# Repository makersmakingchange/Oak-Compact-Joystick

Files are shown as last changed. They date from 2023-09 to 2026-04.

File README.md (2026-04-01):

 # Oak Compact Joystick

<!---  SUMMARY A brief summary of the project. What it does, who it is for, how much it costs.  --->
The Oak Compact Joystick is a medium sized proportional joystick that can be used for adaptive gaming. It has range of motion of approximately ±25° and requires 525 grams-force to fully deflect. This joystick has a cable with a 3.5 mm TRRS audio plug (i.e., headphone jack). It is compatible Microsoft Xbox Adaptive controller as well as the [Forest Joystick Mouse Hub](https://github.com/makersmakingchange/Forest-Joystick-Mouse-Hub) and the [Enabled Controller](https://makersmakingchange.com/project/enabled-controller/).

The Oak Compact Joystick can be used directly as a left or right thumbstick for the Microsoft Xbox Adaptive Controller (XAC) using the X1 or X2 analog input ports. It can also be used with the [Forest Joystick Mouse Hub](https://github.com/makersmakingchange/Forest-Joystick-Mouse-Hub) as a USB Gamepad or USB Mouse.

The Oak Compact Joystick has a set of easily swappable, modular toppers that can be added to make the joystick easier or more comfortable to use.

The Oak Compact Joystick is open assistive technology (OpenAT). Under the terms of the open source licenses, the device may be built, used, and improved upon by anyone.

The current version of the Oak Compact Joystick (v1.0) has been built and user tested.

<!---  PHOTO  --->
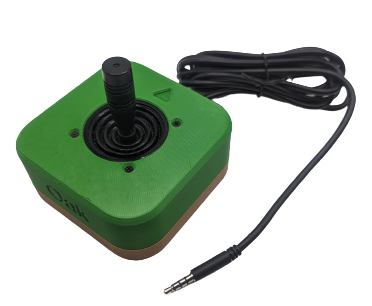
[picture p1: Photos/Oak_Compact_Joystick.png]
An Oak Compact Joystick in a green and brown enclosure.
 
 
<!---  Other available joysticks can be found through the [Joystick Selection Guide](https://makersmakingchange.com/resource/analog-joystick-selection-guide/) --->

Makers Making Change Assistive Device Library Listing: https://www.makersmakingchange.com/s/product/oak-compact-joystick/01tJR00000092x3YAA

## OpenAT Joysticks
This design is part of the [OpenAT Joystick Project](https://github.com/makersmakingchange/OpenAT-Joysticks), a collection of open source designs for digital access and adapted gaming.  

## How to Obtain an Oak Compact Joystick
There are several options for obtaining the device.

### 1. Do it Yourself (DIY) or Do it Together (DIT)

This is an open-source assistive technology, so anyone is free to build it. All of the files and instructions required to build the Oak Compact Joystick are contained within this repository.

### 2. Request a build of this device

If you would like to obtain an Oak Compact Joystick, you may submit a build request through the [MMC Library Listing](https://www.makersmakingchange.com/s/product/oak-compact-joystick/01tJR00000092x3YAA). The requestor is responsible for the cost of materials and any shipping.

### 3. How to build this device for someone else
If you have the skills and equipment to build this device, and would like to donate your time to create the device for someone who needs it, visit the [MMC Maker Wanted](https://makersmakingchange.com/maker-wanted/) section.

## Getting Started

### 1. Read the Makers Checklist

The Makers Checklist in the [Maker Guide](/Documentation/Oak_Joystick_Maker_Guide.pdf) contains a list of tasks to complete to build the device.

### 2. Order the Off-The-Shelf Components

The [Oak Joystick Bill of Materials](/Documentation/Oak_Joystick_BOM.csv) lists all of the parts and components required to build the Oak Compact Joystick.

### 3. Print the 3D Printable components

Print the components needed for the Oak Compact Joystick. Make sure to ask the user if they would like any of the optional prints such as toppers or mount adapters. Refer to the [OpenAT Joystick Setup Guide](https://github.com/makersmakingchange/OpenAT-Joysticks/Resources/OpenAT_Joystick_Setup_Guide.pdf) for detailed mounting options.

The 3D print files for the mounting adapters are located on the [OpenAT Joystick Repository](https://github.com/makersmakingchange/OpenAT-Joysticks/tree/main/Mounting%20Adapters)

All of the files and individual print files can be in the [/Build_Files/3D_Printing_Files](/Build_Files/3D_Printing_Files/) folder.

### 4. Assemble the Oak Compact Joystick

Reference the [Maker Guide](/Documentation/Oak_Joystick_Maker_Guide.pdf) for the tools and steps required to build each portion.

## Files
### Documentation
| Document | Version | Link |
|---|---|---|
| Design Rationale | 1.0 | [Oak_Compact_Joystick_Design_Rationale](/Documentation/Oak_Joystick_Design_Rationale.pdf) |
| Bill of Materials | 1.0 | [Oak_Compact_Joystick_Bill_of_Materials](/Documentation/Oak_Joystick_BOM.csv) |
| Topper Sizing Guide  | 1.0 | [Oak_Compact_Joystick_Topper_Guide](/Documentation/Oak_Joystick_Topper_Guide.pdf)
| Maker Guide | 1.0 | [Oak_Compact_Joystick_Maker_Guide](/Documentation/Oak_Joystick_Maker_Guide.pdf) |
| User Guide | 1.0 | [Oak_Compact_Joystick_User_Guide](/Documentation/Oak_Joystick_User_Guide.pdf) |

### Design Files
<!--- DESIGN FILES If possible, include a copy of original design files to facilitate easy editing and customization. --->
 - [CAD Files](/Design_Files)

### Build Files
<!--- BUILD FILES This section lists links to the various files used to build the device. --->
 - [3D Printing Files](/Build_Files/3D_Printing_files)

## License
<!--- LICENSE Choose an appropriate license. We recommend an open-source hardware compatible license. --->
Everything needed or used to design, make, test, or prepare the Oak Compact Joystick is licensed under the CERN 2.0 Weakly Reciprocal license <https://ohwr.org/project/cernohl/wikis/Documents/CERN-OHL-version-2> (CERN-OHL-W).

Accompanying material such as instruction manuals, videos, and other copyrightable works that are useful but not necessary to design, make, test, or prepare the Oak Compact Joystick are published under a Creative Commons Attribution-ShareAlike 4.0 license <https://creativecommons.org/licenses/by-sa/4.0/> (CC BY-SA 4.0).

Copyright (c) 2023-2025 Neil Squire Society.

This repository describes Open Hardware:
 - Everything needed or used to design, make, test, or prepare the Oak Compact Joystick is licensed under the [CERN 2.0 Weakly Reciprocal license (CERN-OHL-W v2) or later](https://cern.ch/cern-ohl ) .
 - All software is under the [GNU General Public License v3.0 (GPL-3.0)](https://www.gnu.org/licenses/gpl.html).
 - Accompanying material such as instruction manuals, videos, and other copyrightable works that are useful but not necessary to design, make, test, or prepare the Oak Compact Joystick are published under a [Creative Commons Attribution-ShareAlike 4.0 license (CC BY-SA 4.0)](https://creativecommons.org/licenses/by-sa/4.0/) .

You may redistribute and modify this documentation and make products using it under the terms of the [CERN-OHL-W v2](https://cern.ch/cern-ohl).
This documentation is distributed WITHOUT ANY EXPRESS OR IMPLIED WARRANTY, INCLUDING OF MERCHANTABILITY, SATISFACTORY QUALITY AND FITNESS FOR A PARTICULAR PURPOSE.
Please see the CERN-OHL-W v2 for applicable conditions.

Source Location: https://github.com/makersmakingchange/Oak-Compact-Joystick

## Attribution
<!--- ATTRIBUTION Include any information related to the development of the design. This may include who identified the initial challenge, who contributed to the design --->
The documentation template was created by the Makers Making Change program of the Neil Squire Society and is used under a CC BY-SA 4.0 license. It is available at the following link: https://github.com/makersmakingchange/OpenAT-Template

### Contributors
- Stephen Moyer, Neil Squire Society. Design of hardware, enclosure, toppers. Documentation.
- Jake McIvor, Neil Squire Society. Testing and documentation.
- Tyler Fentie, Neil Squire Society. Testing.
- Josie Versloot, Neil Squire Society. Testing.

---

<!-- ABOUT MMC START -->
## About Makers Making Change
[Makers Making Change Logo](https://www.makersmakingchange.com/)

Makers Making Change is a program of [Neil Squire](https://www.neilsquire.ca/), a Canadian non-profit that uses technology, knowledge, and passion to empower people with disabilities.

Makers Making Change leverages the capacity of community based Makers, Disability Professionals and Volunteers to develop and deliver affordable Open Source Assistive Technologies.

 - Website: [www.MakersMakingChange.com](https://www.makersmakingchange.com/)
 - GitHub: [makersmakingchange](https://github.com/makersmakingchange)
 - Bluesky: [@makersmakingchange.bsky.social](https://bsky.app/profile/makersmakingchange.bsky.social)
 - Instagram: [@makersmakingchange](https://www.instagram.com/makersmakingchange)
 - Facebook: [makersmakechange](https://www.facebook.com/makersmakechange)
 - LinkedIn: [Neil Squire Society](https://www.linkedin.com/company/neil-squire-society/)
 - Thingiverse: [makersmakingchange](https://www.thingiverse.com/makersmakingchange/about)
 - Printables: [MakersMakingChange](https://www.printables.com/@MakersMakingChange)

### Contact Us
For technical questions, to get involved, or to share your experience we encourage you to [visit our website](https://www.makersmakingchange.com/) or [contact us](https://www.makersmakingchange.com/s/contact).
<!-- ABOUT MMC END -->

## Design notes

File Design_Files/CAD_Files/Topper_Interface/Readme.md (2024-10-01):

This folder contains the CAD Design files for the Oak Joystick Topper Interface.

The Topper_Interface is the portion that is built in to the Topper. It has an internal thread and can be used to create a custom topper.

The Topper_Collet is a collet that fits between the cylindrical portion of the Oak Joystick and the Topper_Nut.

The Topper_Nut is tightened into the topper. It has an external thread and a hexagonal portion to make it easier to grip / tighten.

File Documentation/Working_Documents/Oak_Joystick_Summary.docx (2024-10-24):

This document is intended to be a summary of a device to make it easier to add to the website.

# Product Information

## Product Name

Oak Compact Joystick

## Device Category

Adapted Toys

Aids for Daily Living (ADL)

Assistive Switches

Communication Aids (AAC)

Computer Access

Environmental Controls

Gaming

Keyguard

Kits

LipSyncs

Mounting

Recreation and Leisure

Seating and Positioning

Switch Interfaces

Writing Aids

## User Value Statement

If you're looking for a joystick that is robust, has a range of topper options, and can be used with any device that accepts an analog joystick input, the Oak Compact Joystick may help get to the root of your joystick needs.

## Designer

Stephen Moyer, Neil Squire Society

# Device Info

## Overview

## The Oak Joystick is a midsized joystick compatible with the XAC or other analog input joystick devices. It has a range of toppers which can be securely attached onto the joystick and removed for ease of modification.

## Disability Type

Select one or more disability types:

Agility / Dexterity

Arthritis

Cognitive

Hearing

Mobility

Mobility

Other

Pain

SCI

Vision

## Disability Type Description

Great for anyone looking for a more traditional joystick experience and feel, with the ability to apply a range of custom toppers to maximize comfort in use.

## How To Use

For full instructions please refer to the User Guide.

Usage

Using the Joystick

1. Plug the 3.5 mm TRRS cable from the joystick into the host device (such as the Xbox Adaptive Controller). If using the Xbox Adaptive Controller, plug it into X1 to use at the left joystick, or plug into X2 to use as the right joystick.
2. Ensure the arrow on the joystick is pointing in the “up/forward” direction, away from the user.
3. Mount the device if needed (see below).
4. Move joystick as you would with a standard controller. Estimated Cost

Compatibility

This device is compatible with the XAC, Enabled Controller, and any other device that accepts a TRRS analog joystick input.

The estimated material cost of the device:

$0 - $10

$11 - $25

$26 - $50

$51 - $100

$101 - $250

$250+

## Attribution

Hardware, topper, and enclosure design: Stephen Moyer, Neil Squire

The documentation template was created by Makers Making Change / Neil Squire and is used under a CC BY-SA 4.0 license. It is available at the following link: https://github.com/makersmakingchange/OpenAT-Template

# Maker Info

## Project Skills

3D Printing

Custom PCB

Electronics

Laser Cutting

Mechanics

Other

Software

Soldering

Woodworking

## Skills Description

This is an intermediate build requiring soldering and 3D printing.

## Tools Needed

3D Printer

Common Hand Tools

Common Power Tools

Laser Cutter

Soldering Iron

Specialized Tooling

## Print time (hrs)

4

## Assembly time (hrs)

1

## Build Instructions

For full instructions please refer to the Assembly Guide (https://github.com/makersmakingchange/Oak-Compact-Joystick/blob/v1.0/Documentation/Oak_Joystick_Maker_Guide.pdf).

Print Settings:

- 0.2mm Layer Height
- 20% infill
- Some optional parts require supports

## Download Link

https://github.com/makersmakingchange/Oak-Compact-Joystick/archive/refs/heads/v1.0.zip

## Project Link

https://github.com/makersmakingchange/Oak-Compact-Joystick/tree/v0.9

# License

## License

Hardware: CERN 2.0 Weakly Reciprocal license

Documentation: Attribution-ShareAlike4.0 International

© 2023 by Neil Squire Society. This work is licensed under the CC BY SA 4.0 License: http://creativecommons.org/licenses/by-sa/4.0 Files available at https://github.com/makersmakingchange/Oak-Compact-Joystick Page 1 of 2

V1.0.2 | October 2024 Oak Compact Joystick Summary

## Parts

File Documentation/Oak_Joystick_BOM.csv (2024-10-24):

Oak Compact Joystick |  |  |  |  |  |  |  | Unit Cost | Total Cost | Total Print time (hr) | Total filament (g)
Version: V1.0.2 |  | Last Updated: 2024-Oct-07 |  |  |  |  |  | $61.12 | $61.12 | 3.87 | 63.26
Commercial Parts
ID | Part Name | Supplier | QTY | QTY/PKG | $/PKG | PKG QTY | $/Unit | Extended | Total | Link
 | TRRS Audio Cable | DigiKey | 1 | 1 | $7.29 | 1 | $7.29 | $7.29 | $7.29 | https://www.digikey.ca/en/products/detail/tensility-international-corp/10-00341/2350244
 | Adafruit Mini Analog Joystick | DigiKey | 1 | 1 | $31.43 | 1 | $31.43 | $31.43 | $31.43 | https://www.digikey.ca/en/products/detail/adafruit-industries-llc/3102/6152821
 | Wire, 26 AWG, 1 ft | DigiKey | 1 | 1 | $0.72 | 1 | $0.72 | $0.72 | $0.72 | https://www.digikey.ca/en/products/detail/cnc-tech/1569-26-1-0500-005-1-TS/15853670
 | Screw, #4 self-tapping 3/8" length | DigiKey | 4 | 1 | $0.63 | 4 | $0.63 | $2.52 | $2.52 | https://www.digikey.ca/en/products/detail/serpac/6005/307599
 | Cable tie, 4" | DigiKey | 1 | 1 | $0.17 | 1 | $0.17 | $0.17 | $0.17 | https://www.digikey.ca/en/products/detail/3m/CT4NT18-M/2721151
 | Hex nut, M3 | DigiKey | 2 | 1 | $0.27 | 2 | $0.27 | $0.54 | $0.54 | https://www.digikey.ca/en/products/detail/keystone-electronics/4708/4499301
 | Digikey Shipping (<$100 order) | DigiKey | 1 | 1 | $8.00 | 1 | $8.00 | $8.00 | $8.00
 |  |  |  |  |  |  | $- | $- | $-
3D Printed Parts ESTIMATED PRICING USING 1KG ROLL COST: |  | $30.00
ID | Part | Material | QTY | Mass (g) / Unit | Time / Unit |  | Print Time (Min) | Estimated Price |  | Link
 | Oak Enclosure Top | PLA | 1 | 28 | 130 |  | 130 | $0.83
 | Oak Enclosure Bottom | PLA | 1 | 27 | 102 |  | 102 | $0.82
 | Joystick Camera Mount (Optional) | PLA | 0 | 9 | 54 |  | 0 | $0.26
 | Oak Topper Collet (Optional) | PLA | 1 | 1 | 9 |  | 9 | $0.03
 | Oak Topper Nut (Optional) | PLA | 1 | 4 | 20 |  | 20 | $0.12
 | Oak Topper Wrench (Optional) | PLA | 1 | 5 | 26 |  | 26 | $0.15
 | Small_Ball Topper | PLA | 0 | 10 | 23 |  | 0 | $0.30
 | Medium_Ball_Topper | PLA | 0 | 16 | 30 |  | 0 | $0.48
 | Large_Ball_Topper | PLA | 0 | 24 | 40 |  | 0 | $0.72
 | Small_Concave_Topper | PLA | 0 | 9 | 20 |  | 0 | $0.27
 | Medium_Concave_Topper | PLA | 0 | 11 | 24 |  | 0 | $0.33
 | Large_Concave_Topper | PLA | 0 | 13 | 28 |  | 0 | $0.39
 | Small_Convex_Topper | PLA | 0 | 5 | 12 |  | 0 | $0.15
 | Medium_Convex_Topper | PLA | 0 | 7 | 16 |  | 0 | $0.21
 | Large_Convex_Topper | PLA | 0 | 10 | 21 |  | 0 | $0.30
 | Small_Goalpost_Topper | PLA | 0 | 12 | 31 |  | 0 | $0.36
 | Medium_Goalpost_Topper | PLA | 0 | 15 | 36 |  | 0 | $0.45
 | Large_Goalpost_Topper | PLA | 0 | 17 | 40 |  | 0 | $0.51
 | Small_Stick_Topper | PLA | 0 | 29 | 75 |  | 0 | $0.87
 | Medium_Stick_Topper | PLA | 0 | 42 | 102 |  | 0 | $1.26
 | Large_Stick_Topper | PLA | 0 | 55 | 122 |  | 0 | $1.65
 |  |  |  |  |  |  |  | $-
Alternatives
ID | Part and description |  |  |  |  |  |  |  |  | Link
 | M3 hex nuts | Local hardware store
 | Wire, 24 or 26 AWG | Local hardware store
 | #4 3/8" screws | Digikey | 4 | 100 | $7.82 | 1 | $0.08 | $0.31 | $7.82 | https://www.amazon.ca/gp/product/B00GI86MW8
 | Hex nut, M3 | Digikey | 2 | 100 | $0.06 | 1 | $0.00 | $0.00 | $0.06 | https://www.digikey.ca/en/products/detail/b-f-fastener-supply/MHNZ-003/274973
 | JH-D202X-R4 Joystick | Adafruit |  |  |  |  |  |  |  | https://www.adafruit.com/product/3102
 | JH-D202X-R4 Joystick | Exiron - Amazon |  |  |  |  |  |  | 27.22 | https://www.amazon.ca/Exiron-Joystick-Potentiometer-JH-D202X-R2-Thermistor/dp/B07CWWM9WF
 | JH-D202X-R4 Joystick | Adafruit - Mouser |  |  |  |  |  |  | 28.93 | https://www.mouser.ca/ProductDetail/Adafruit/3102
 | JH-D202X-R4 Joystick | Yan's Tools Store - AliExpress |  |  |  |  |  |  | 8.2 | https://www.aliexpress.com/item/1005003469274285.html

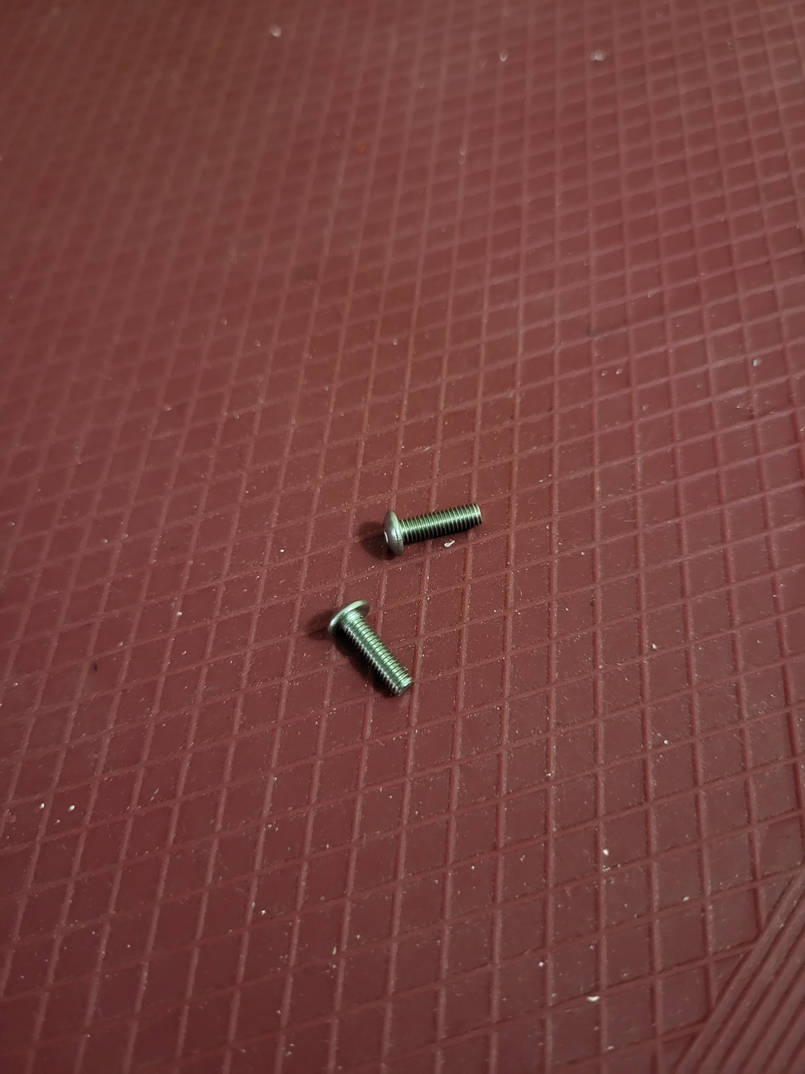
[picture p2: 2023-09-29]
Documentation/Working_Documents/Assets/Component_Photos/M3_screws.jpg

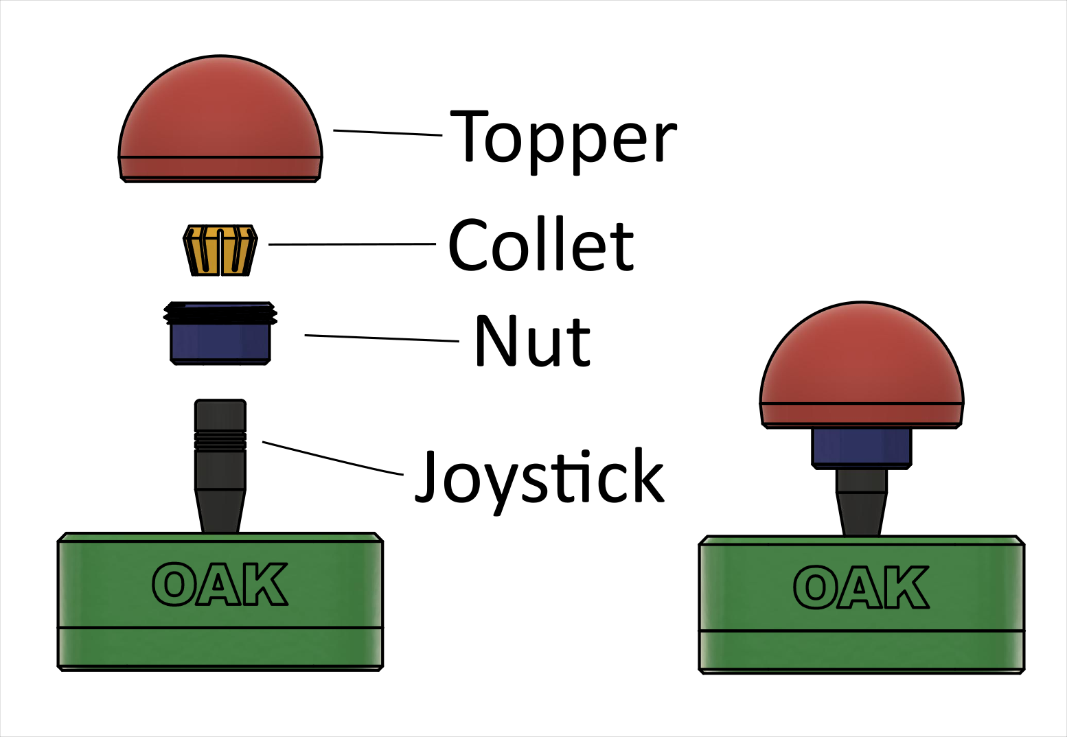
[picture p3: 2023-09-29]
Documentation/Working_Documents/Assets/Oak_Modular_Topper_Components.png

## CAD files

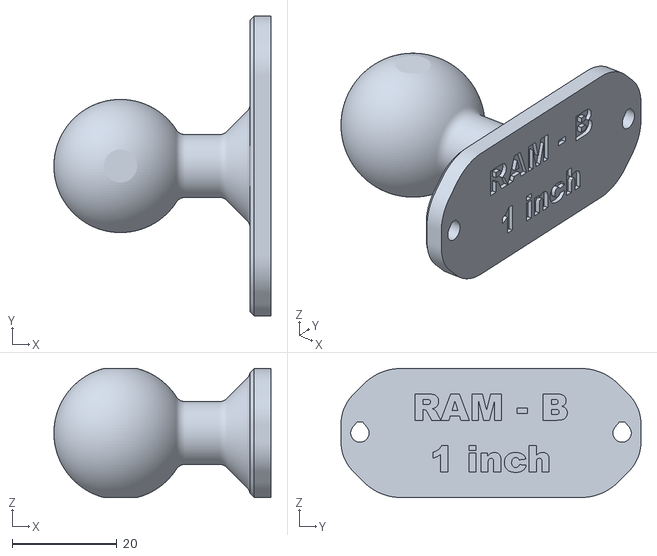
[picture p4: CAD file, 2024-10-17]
Build_Files/3D_Printing_Files/Joystick_RAM_B_Mount_Adapter.stl
41.4 x 57.2 x 24.6

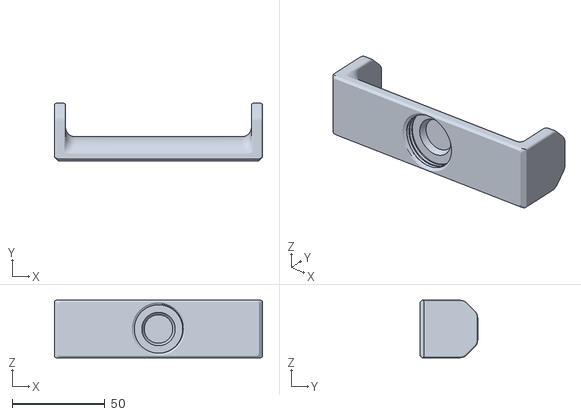
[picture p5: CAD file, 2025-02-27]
Build_Files/3D_Printing_Files/Toppers/Large/Large_Goalpost_Topper.stl
112.0 x 31.0 x 31.0

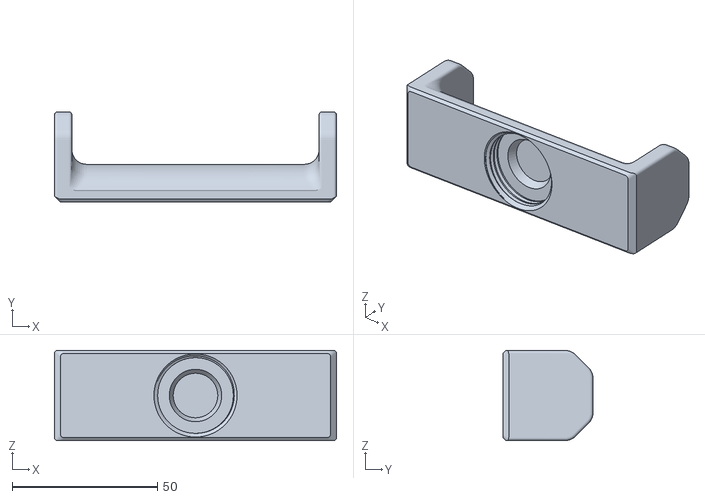
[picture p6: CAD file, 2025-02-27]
Build_Files/3D_Printing_Files/Toppers/Medium/Medium_Goalpost_Topper.stl
97.0 x 31.0 x 31.0

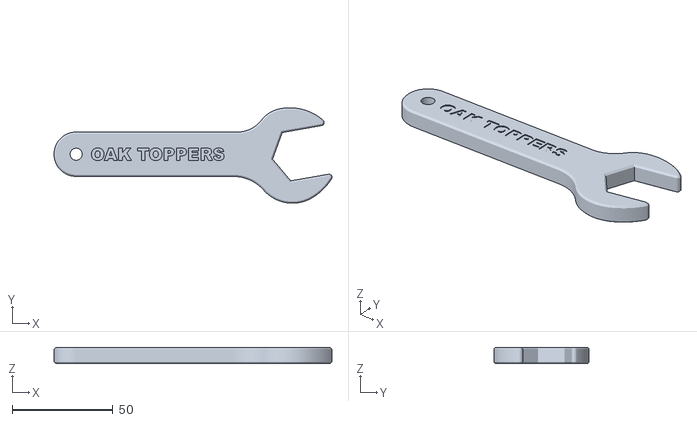
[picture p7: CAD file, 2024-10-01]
Build_Files/3D_Printing_Files/Toppers/Oak_Topper_Wrench.stl
137.7 x 47.2 x 8.00

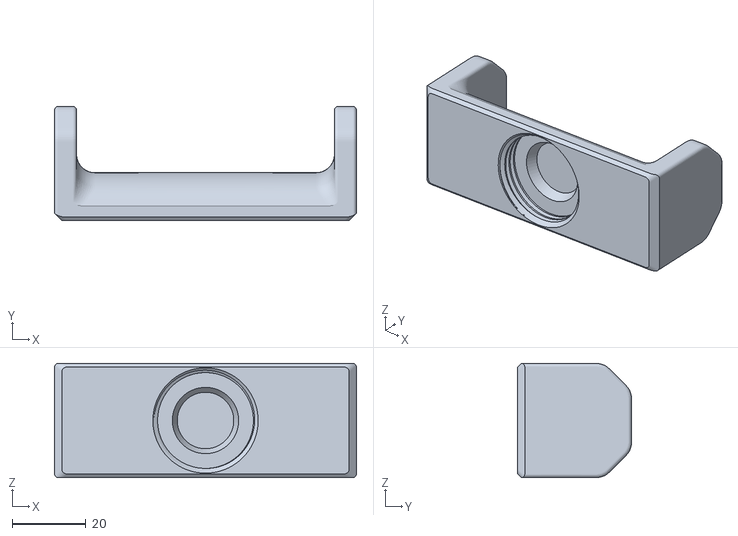
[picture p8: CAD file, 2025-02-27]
Build_Files/3D_Printing_Files/Toppers/Small/Small_Goalpost_Topper.stl
82.0 x 31.0 x 31.0

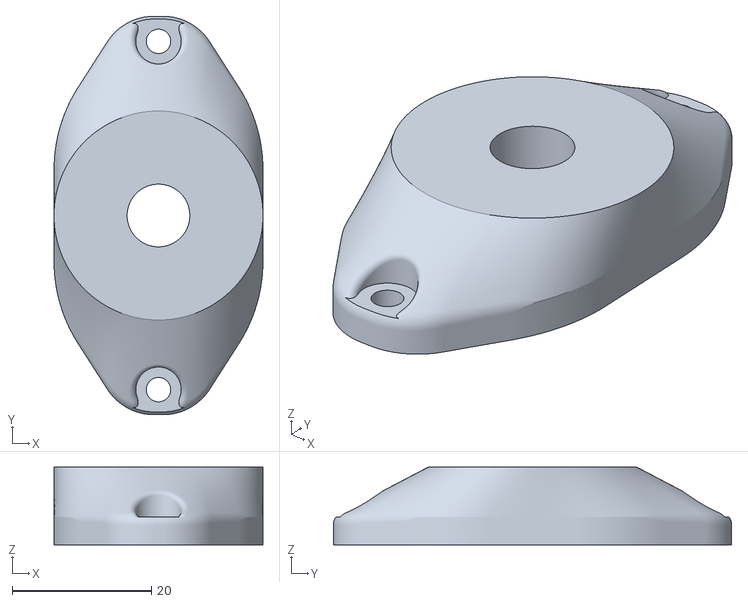
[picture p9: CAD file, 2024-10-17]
Build_Files/3D_Printing_Files/Joystick_Camera_Mount_Adapter.stl
30.0 x 57.2 x 11.1

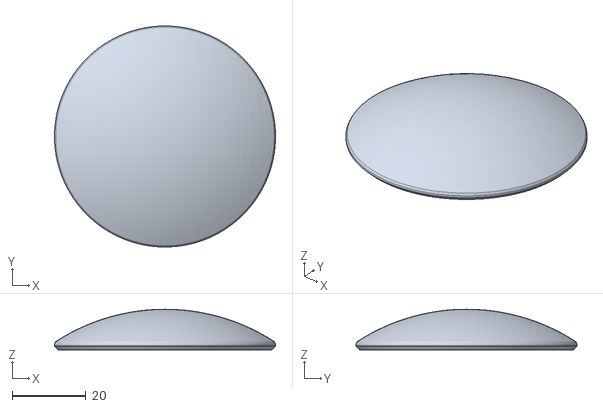
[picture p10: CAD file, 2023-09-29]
Build_Files/3D_Printing_Files/Toppers/Large/Large_Convex_Topper.stl
60.0 x 60.0 x 11.0

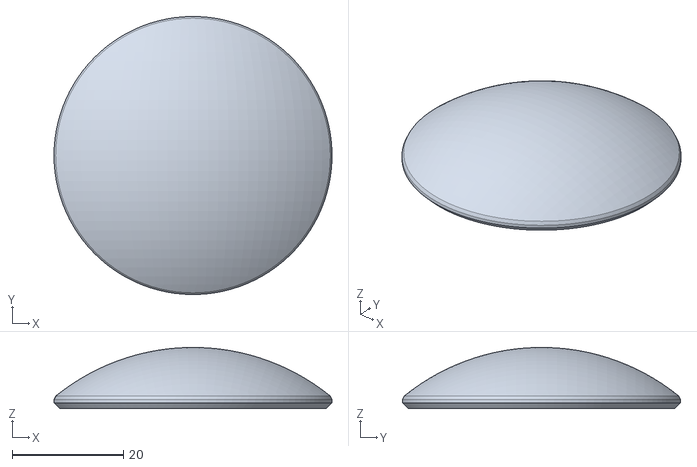
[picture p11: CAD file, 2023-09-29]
Build_Files/3D_Printing_Files/Toppers/Medium/Medium_Convex_Topper.stl
50.0 x 50.0 x 11.0

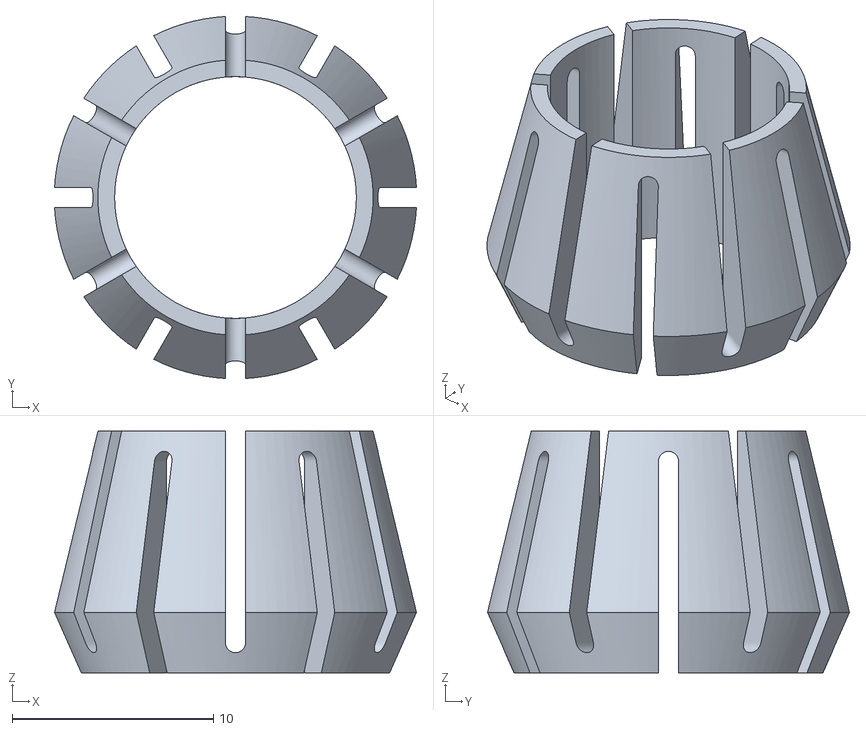
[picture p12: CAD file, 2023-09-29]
Build_Files/3D_Printing_Files/Toppers/Oak_Topper_Collet.stl
18.0 x 18.0 x 12.0

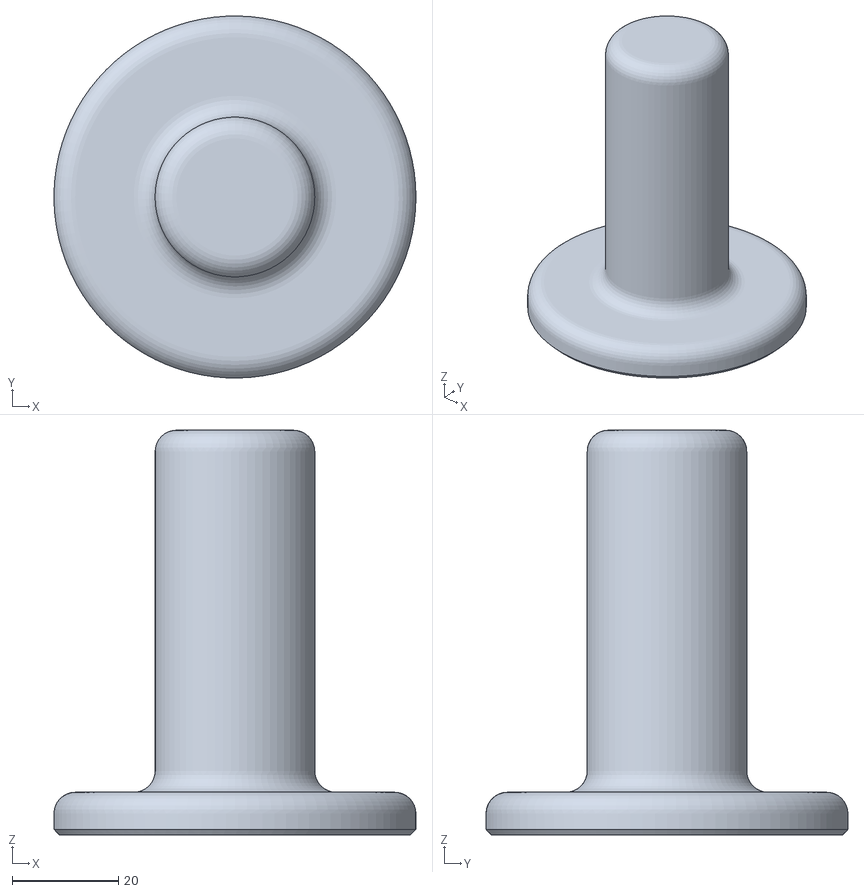
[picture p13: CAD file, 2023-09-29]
Build_Files/3D_Printing_Files/Toppers/Small/Small_Stick_Topper.stl
68.0 x 68.0 x 76.0

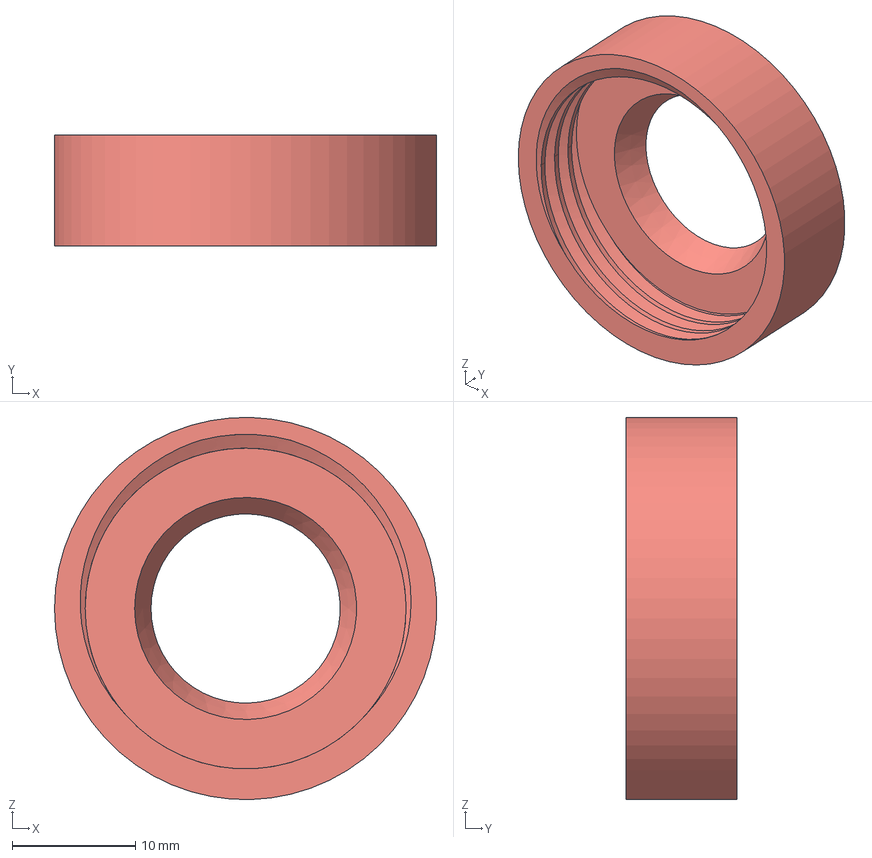
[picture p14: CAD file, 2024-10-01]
Design_Files/CAD_Files/Topper_Interface/Oak_Topper_Interface.step
31.0 x 9.00 x 31.0 mm

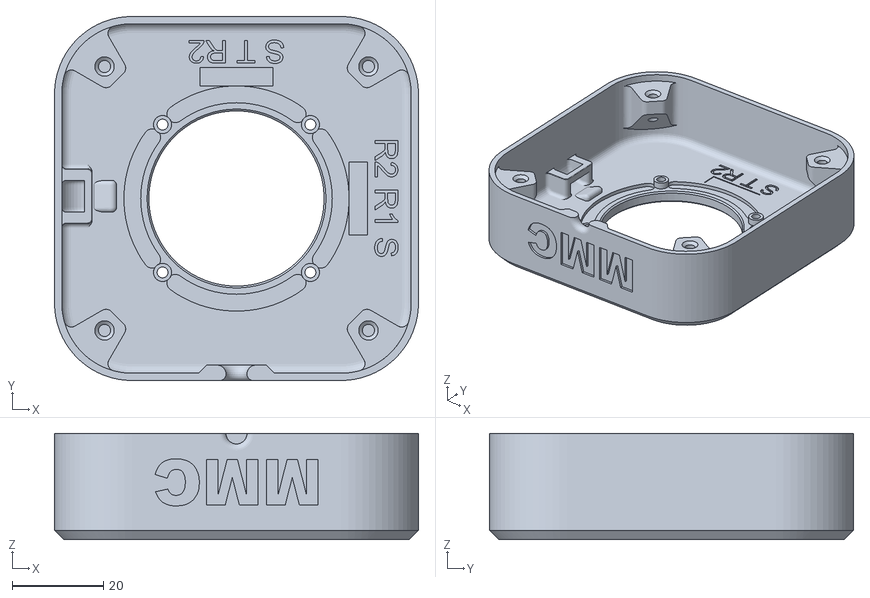
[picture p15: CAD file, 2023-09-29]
Build_Files/3D_Printing_Files/Oak_Enclosure_Top.stl
80.0 x 80.0 x 23.3

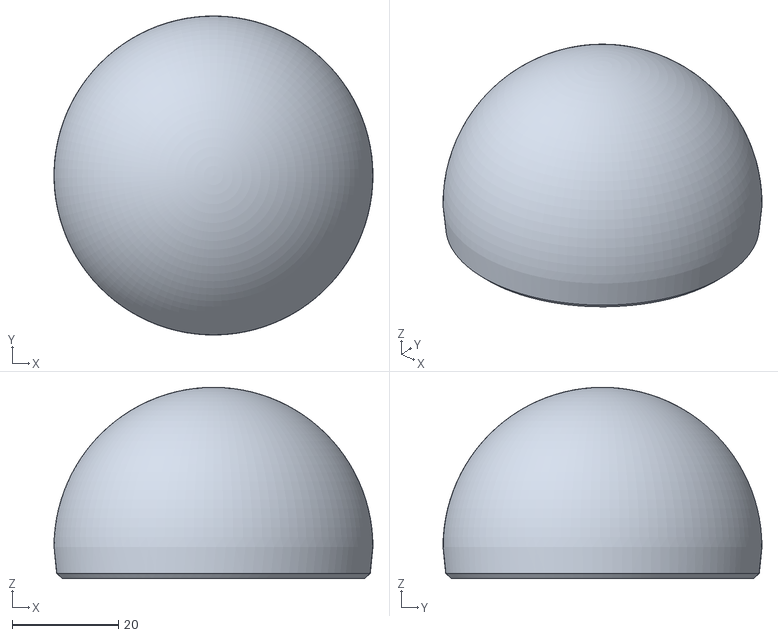
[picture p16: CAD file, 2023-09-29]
Build_Files/3D_Printing_Files/Toppers/Large/Large_Ball_Topper.stl
60.0 x 60.0 x 36.0

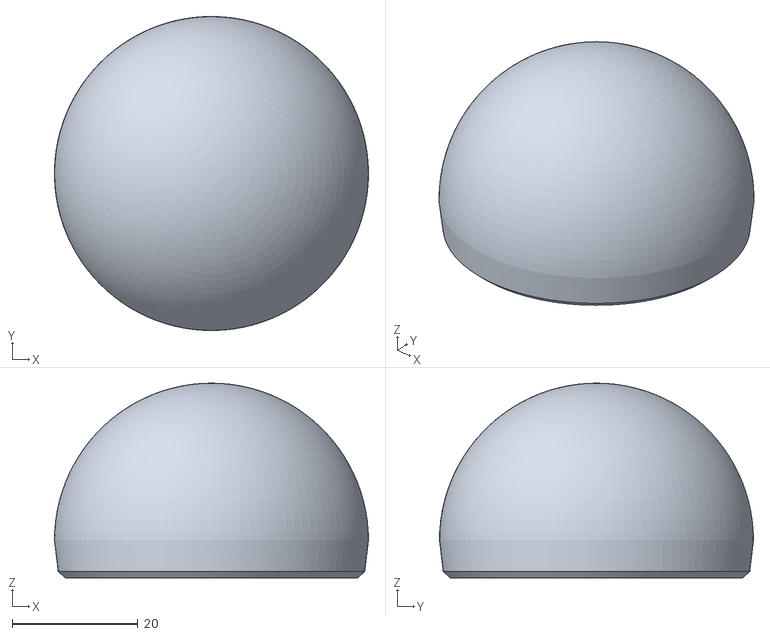
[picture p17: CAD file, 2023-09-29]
Build_Files/3D_Printing_Files/Toppers/Medium/Medium_Ball_Topper.stl
50.0 x 50.0 x 31.0

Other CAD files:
Design_Files/CAD_Files/Topper_Interface/Oak_Topper_Wrench.step
Build_Files/3D_Printing_Files/Toppers/Small/Small_Ball_Topper.stl
Design_Files/CAD_Files/Topper_Interface/Oak_Topper_Collet.step
Build_Files/3D_Printing_Files/Oak_Enclosure_Bottom.stl
Build_Files/3D_Printing_Files/Toppers/Large/Large_Concave_Topper.stl
Build_Files/3D_Printing_Files/Toppers/Large/Large_Stick_Topper.stl
Build_Files/3D_Printing_Files/Toppers/Medium/Medium_Concave_Topper.stl
Build_Files/3D_Printing_Files/Toppers/Medium/Medium_Stick_Topper.stl
Build_Files/3D_Printing_Files/Toppers/Oak_Topper_Nut.stl
Build_Files/3D_Printing_Files/Toppers/Small/Small_Concave_Topper.stl
Build_Files/3D_Printing_Files/Toppers/Small/Small_Convex_Topper.stl
Design_Files/CAD_Files/Joystick RAM Mount Adapter v5.f3d
Design_Files/CAD_Files/Joystick_Camera_Mount Narrow v3.f3d
Design_Files/CAD_Files/Oak_Compact_Joystick_Enclosure.f3d
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

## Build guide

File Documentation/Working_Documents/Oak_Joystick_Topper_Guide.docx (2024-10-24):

# What is a topper?

A topper is any support, grip, or other structure added to the joystick to make it easier and more comfortable to use the joystick. Toppers can be made of a variety of materials and be customized to the user.

The Oak Joystick has a modular topper that can be easily swapped. There are three parts to the modular topper: the topper, a collet, and a nut. A variety of topper styles are available and different sizes of each. It is also possible to create a topper with a custom style or size. A wrench tool is available to make it easier to tighten and loosen the nut.

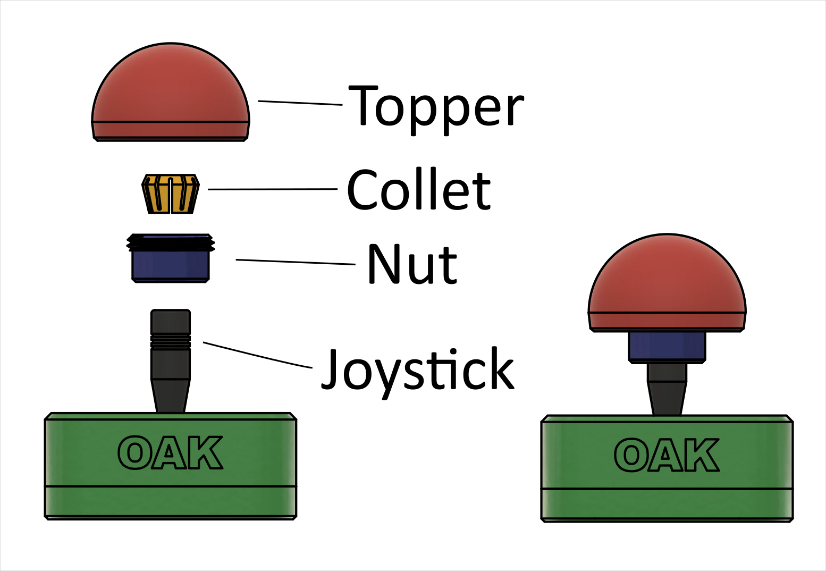
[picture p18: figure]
Oak Modular Topping system diagram

# What styles of toppers are there?

There are currently five styles of 3D printable topper: a hemispheric ball topper, a concave disc topper, a convex disc topper, a goalpost topper, and a stick topper.

Table 1. Topper Styles

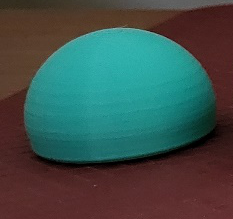
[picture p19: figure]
A photo of the ball, concave, convex, goalpost, and stick toppers from left to right printed in teal PLA.
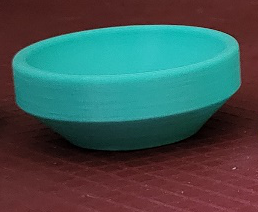
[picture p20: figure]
A photo of the ball, concave, convex, goalpost, and stick toppers from left to right printed in teal PLA.
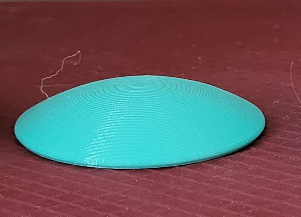
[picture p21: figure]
A photo of the ball, concave, convex, goalpost, and stick toppers from left to right printed in teal PLA.
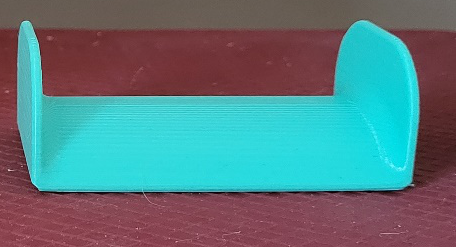
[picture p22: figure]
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
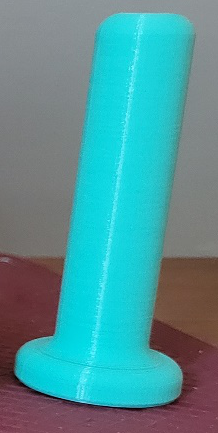
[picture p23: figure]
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

Ball | Concave | Convex | Goalpost | Stick

# Which topper will be best for me?

The five topper styles are available in small, medium, and large sizing. Dimensions and scaled printouts are available to select which size is best for you.

## Ball Topper

The ball topper is ideal for someone who wants a large grip or larger target to hit to move the joystick. Note that this topper is the top half of a ball, not a full ball.

Topper | Dimension | Small | Medium | Large | Image
Ball Topper | Diameter [mm] | 40 | 50 | 60

## Concave Disc Topper

That concave disc is best for someone without the capability to grip the joystick or other toppers. This topper is like a small cup that you can push on from the inside. It would be ideal for users who want to use their chin, or heel.

Topper | Dimension | Small | Medium | Large | Image
Concave Topper | Diameter [mm] | 40 | 50 | 60

## Convex Disc Topper

Topper | Dimension | Small | Medium | Large | Image
Convex Topper | Diameter [mm] | 40 | 50 | 60

The convex disc is ideal for someone with low grip capabilities but has good gross motor control and can rest their hand independently on the topper.

## Goalpost Topper

The goalpost topper is ideal for users who may not be able to independently put their hand on the topper, as the sidewalls will help to keep their hand on the joystick.

Topper | Dimension | Small | Medium | Large | Image

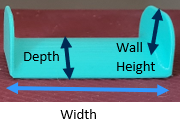
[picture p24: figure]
Goalpost topper showing width, depth, and wall height dimensions.

Goalpost Topper | Width [mm] | 70 | 85 | 100
| Depth [mm] | 31 | 31 | 31
| Wall Height [mm] | 15 | 18 | 20

## Stick Topper

The stick topper is a traditional joystick grip that essentially extends the existing stick of the joystick. It features a brim around the base to keep the user’s hand from slipping down the joystick as well.

Topper | Dimension | Small | Medium | Large | Image

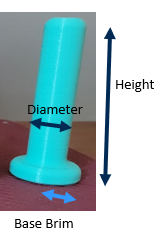
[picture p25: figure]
Stick topper showing diameter, height, and base brim dimensions.

Stick Topper | Grip diameter [mm] | 30 | 35 | 40
| Height [mm] | 70 | 85 | 100
| Base Brim [mm] | 15 | 20 | 25

## Custom Topper Sizes

If none of the pre-configured options works, the toppers can be further modified through the original CAD files (Fusion 360) if different dimensions are desired.

## Custom Topper Design

Custom toppers can be designed through CAD programs such as Fusion 360 to create a topper specific to you. The Design Rationale (https://github.com/makersmakingchange/Oak-Compact-Joystick/blob/v1.0/Documentation/Oak_Compact_Joystick_Design_Rationale.pdf) for the Oak Joystick contains all the relevant information to create a topper that will work with the current topper interface system, or to create a simple press-fit topper. The Collet.f3d file can also be expanded upon by designing a topper on and around the “Topper_Side” component.

Alternatively, other materials such as Instamorph, wood, clay, etc. can be used to create a custom topper.

# Topper Sizing Printouts

The following sheets can be printed out to see the actual size of the available toppers.

© 2023-2024 by Neil Squire Society. This work is licensed under the CC BY SA 4.0 License: http://creativecommons.org/licenses/by-sa/4.0 Files available at https://github.com/makersmakingchange/Oak-Compact-Joystick Page 1 of 2

V1.0.2 | October 2024 Oak Compact Joystick Topper Guide

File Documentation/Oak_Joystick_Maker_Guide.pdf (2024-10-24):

## Oak Compact Joystick

## MAKER GUIDE

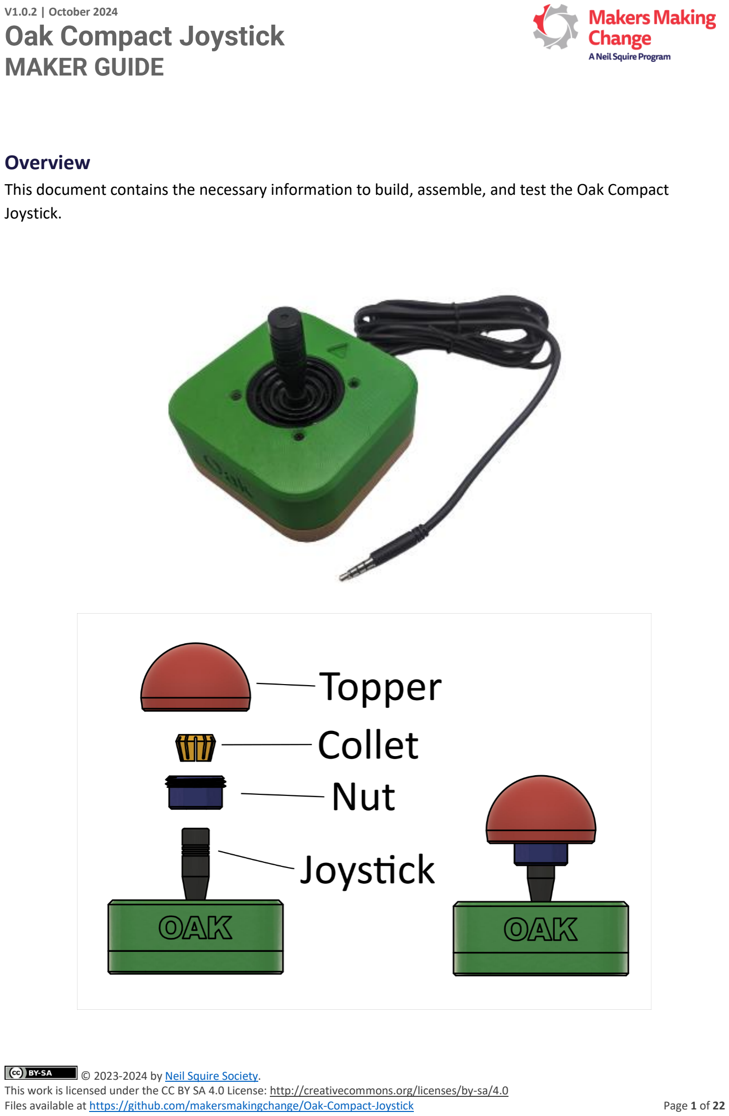
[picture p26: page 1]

V1.0.2 | October 2024

© 2023-2024 by Neil Squire Society. (https://www.neilsquire.ca/) This work is licensed under the CC BY SA 4.0 License: http://creativecommons.org/licenses/by-sa/4.0
Files available at https://github.com/makersmakingchange/Oak-Compact-Joystick | Page 1 of 22

### Overview

This document contains the necessary information to build, assemble, and test the Oak Compact Joystick.

## MAKER GUIDE

Files available at https://github.com/makersmakingchange/Oak-Compact-Joystick | Page 2 of 22

### Contents

## MAKER GUIDE

Files available at https://github.com/makersmakingchange/Oak-Compact-Joystick | Page 3 of 22

## MAKER GUIDE

Files available at https://github.com/makersmakingchange/Oak-Compact-Joystick | Page 4 of 22

This list provides an overview of the steps required to build and deliver the device.

### Maker To Do List

Read through the Maker Guide to become familiar with required components, tools, supplies, safety gear, and overall assembly steps.
Ask the user if they would if they have a device to connect the joystick to.
- Xbox Adaptive Controller (https://www.xbox.com/en-CA/accessories/controllers/xbox-adaptive-controller)
- Forest Joystick Mouse Hub (https://github.com/makersmakingchange/Forest-Joystick-Mouse-Hub)
- Enabled Controller Mini (https://github.com/makersmakingchange/Enabled-Controller-Mini/tree/main)
- Enabled Controller (https://github.com/milador/Enabled-Controller)
- Other Analog to USB joystick hub
Ask the user if they would like any joystick toppers. Reference the Topper Guide. Ask the user if they would like a specific mounting solution.
Talk to User about customization options (e.g., colour, any special requests, etc.). Order hardware components.
3D print all 3D printed components.
Gather tools, supplies, and safety equipment.
Assemble the device.
Test device.
Print “User Guide”

### Items to Give to User

Assembled, tested joystick Joystick toppers (if requested) Mounting Adapters (if requested) Printed “User Guide”

## MAKER GUIDE

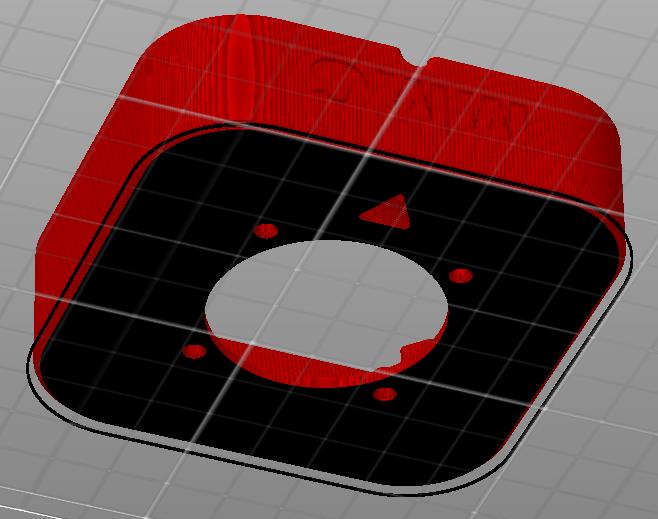
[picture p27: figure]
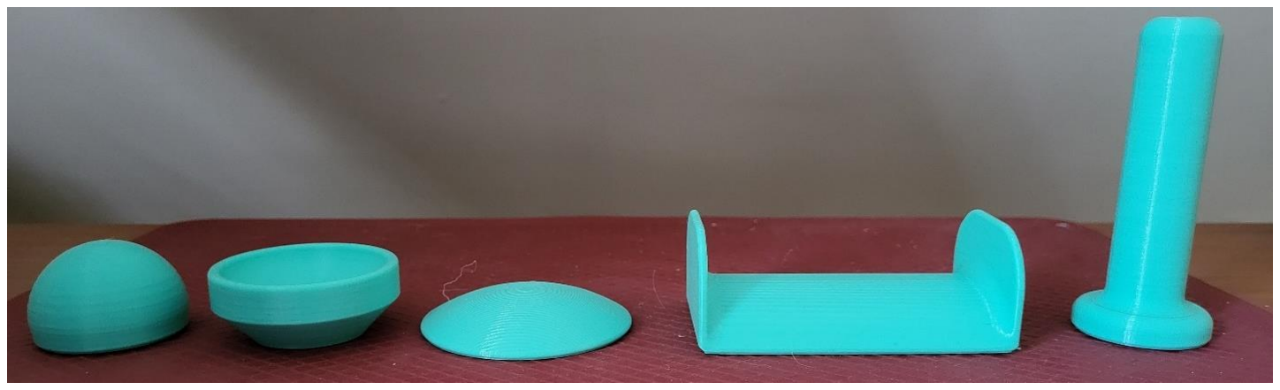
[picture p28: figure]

Files available at https://github.com/makersmakingchange/Oak-Compact-Joystick | Page 5 of 22

### Customization Guide

### Joystick

The enclosure can be printed in the user’s desired colour(s). Colour swaps can be done to further customize the joystick and make the forward arrow on the top stand out more.

### Toppers

3D printed joystick toppers can be added to the joystick. Current topper type include ball, concave, convex, goalpost, and stick (shown left to right). Each comes in sizes small, medium, and large, which can be seen in the Topper Guide, (https://github.com/makersmakingchange/Oak-Compact-Joystick/tree/v1.0/Documentation/Working_Documents/Oak_Joystick_Topper_Guide.docx) or can be further modified through the original design files. (https://github.com/makersmakingchange/Oak-Compact-Joystick/tree/v1.0/Design_Files)

### Mounting

Mount adapters can be added for custom mounting solutions. Current mounting options include nonslip pads, hook and loop fastener, and a ¼-20 camera mount adapter. Further mounting instructions can be found in the OpenAT Joystick Setup Guide. (https://github.com/makersmakingchange/OpenAT-Joysticks/Resources/OpenAT_Joystick_Setup_Guide.pdf)

## MAKER GUIDE

Files available at https://github.com/makersmakingchange/Oak-Compact-Joystick | Page 6 of 22

### 3D Printing Guide

### 3D Printing Summary

Metrics | Joystick Enclosure | Topper Interface
Total Print Time (min) | 4h4m | 0h56m
Total Number of Components | 2 | 2
Typical Total Mass (g) | 52 | 6
Typical Number of Print Setups | 1 | 1

### 3D Printing Settings

Joystick Enclosure - REQUIRED
Print File Name | Qty | Total Print Time (hr:min) | Mass (g) | Infill (%) | Support (Y/N) | Layer Height/ Nozzle Diameter(mm) | Notes
Oak_Enclosure_Top.stl | 1 | 2:22 | 29 | 20 | N | 0.2/0.4
Oak_Enclosure_Bottom.stl | 1 | 1:42 | 23 | 20 | N | 0.2/0.4

Oak Topper Interface – OPTIONAL, Required for Topper
Print File Name | Qty | Total Print Time (hr:min) | Mass (g) | Infill (%) | Support(Y/N) | Layer Height/ Nozzle Diameter(mm) | Notes
Oak_Topper_Nut.stl | 1 | 0:39 | 5 | 20 | N | 0.2/0.4
Oak_Topper_Collet.stl | 1 | 0:17 | 1.04 | 20 | N | 0.2/0.4
Oak_Topper_Wrench.stl | 1 | 0:26 | 5 | 20 | N | 0.2/0.4

Toppers* - OPTIONAL
Print File Name | Qty | Total Print Time (hr:min) | Mass (g) | Infill (%) | Support(Y/N) | Layer Height/ Nozzle Diameter(mm) | Notes
Medium_Ball_Topper.stl | 1 | 1:16 | 18 | 10 | N | 0.2/0.4 | Print with 4 perimeters
Medium_Concave_Topper.stl | 1 | 1:07 | 15 | 10 | N | 0.2/0.4 | Print with 4 perimeters
Medium_Convex_Topper.stl | 1 | 0:42 | 9 | 10 | N | 0.2/0.4 | Print with 4 perimeters

## MAKER GUIDE

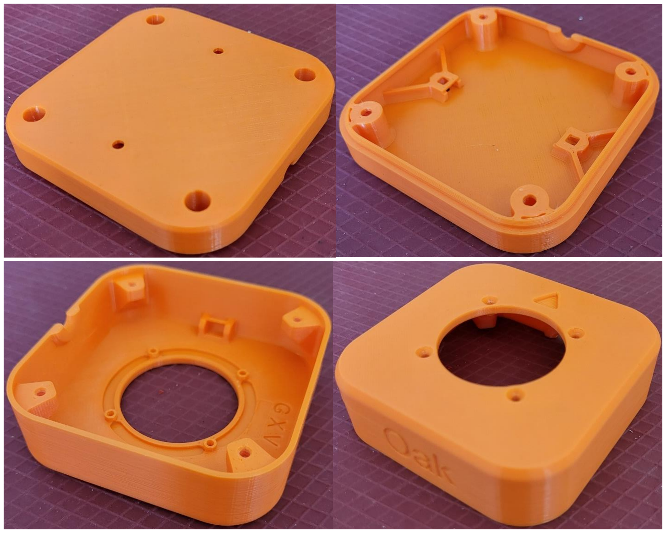
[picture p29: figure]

Files available at https://github.com/makersmakingchange/Oak-Compact-Joystick | Page 7 of 22
Medium_Goalpost_Topper.stl | 1 | 1:30 | 18 | 10 | N | 0.2/0.4 | Print with 4 perimeters
Medium_Stick_Topper.stl | 1 | 3:13 | 50 | 10 | N | 0.2/0.4 | Print with 4 perimeters

*Note that only the medium topper sizes are shown in the 3D printing Settings table. There are small
and large sizes available, as well as the original Fusion 360 files that can be modified to specific
dimensions.

### Post-Processing

- Remove any supports from the Camera mount adapter if it is printed.
- Clear any stringing in the collet if it is printed.

### Examples of Quality Prints

Photos of Enclosure 3D Prints

## MAKER GUIDE

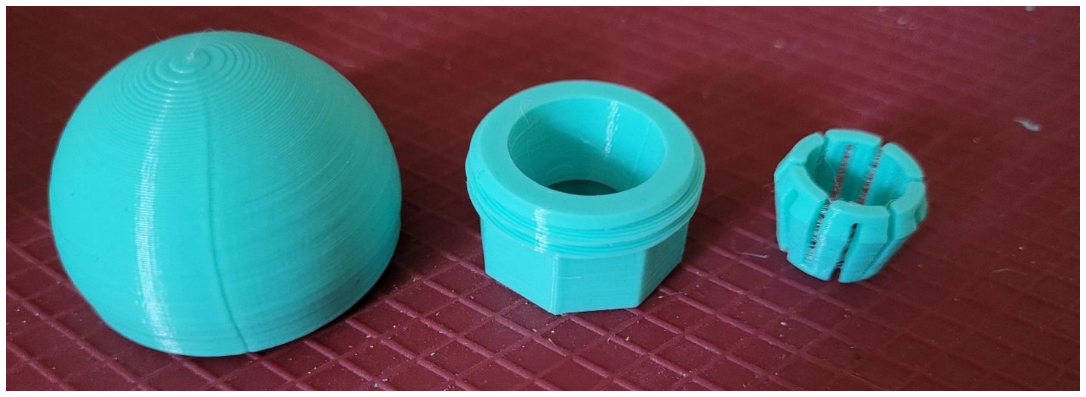
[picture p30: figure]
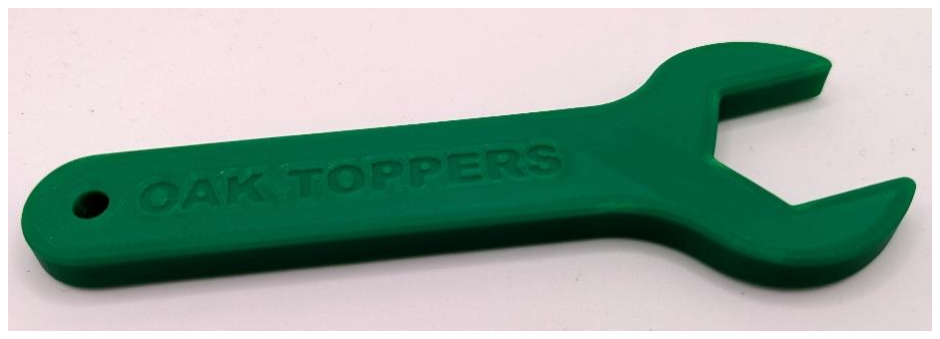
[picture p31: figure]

Files available at https://github.com/makersmakingchange/Oak-Compact-Joystick | Page 8 of 22

Photos of Topper 3D Prints

Photo of Wrench Topper

## MAKER GUIDE

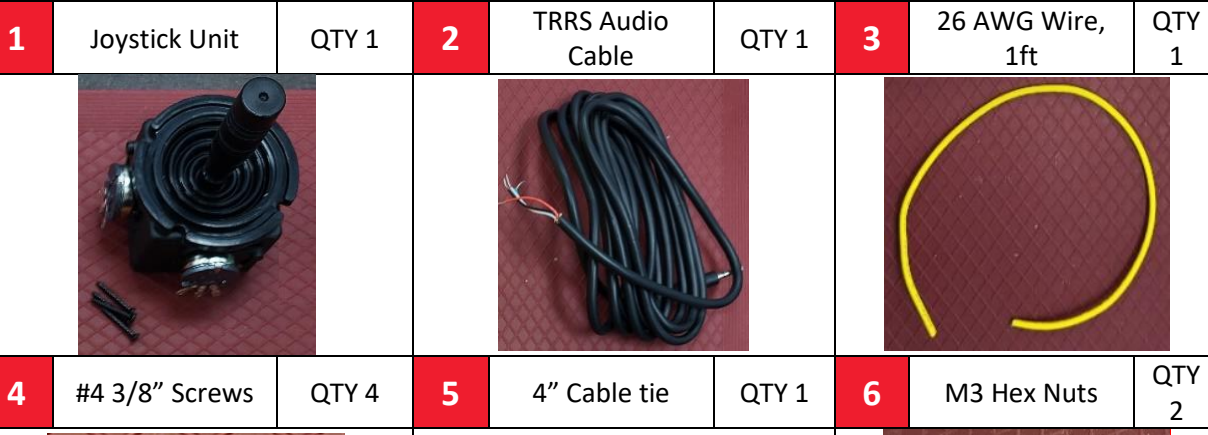
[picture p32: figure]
Joystick Unit; QTY 1; TRRS Audio; Cable; 26 AWG Wire, 1ft; #4 3/8” Screws; QTY 4; 4” Cable tie; M3 Hex Nuts; QTY

Files available at https://github.com/makersmakingchange/Oak-Compact-Joystick | Page 9 of 22

### Assembly Guide

### Required Components

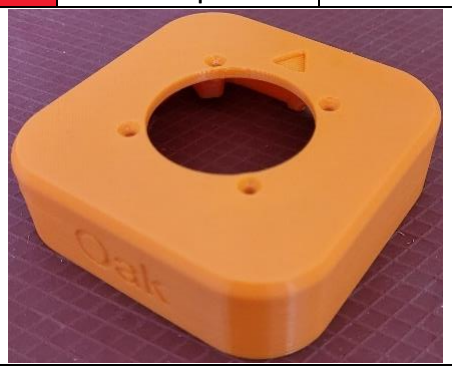
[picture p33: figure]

7

Oak Enclosure
Top | QTY 1 | 8

Oak Enclosure
Bottom | QTY 1

### Required Tools

- #1 Phillips Screwdriver
- Wire Cutters
- Wire Strippers
- Soldering Iron and Solder
- Multimeter (with continuity testing capabilities)

### Optional Tools

- Tweezers

### Required Personal Protective Equipment (PPE)

- Safety Goggles

## MAKER GUIDE

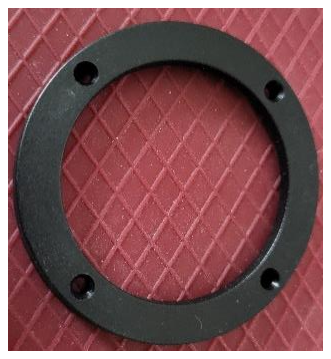
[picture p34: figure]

Files available at https://github.com/makersmakingchange/Oak-Compact-Joystick | Page 10 of 22

### Joystick Assembly

Step 1: Remove the Ring

The Adafruit Mini Analog Joystick comes with a ring that screws into the top. You will not need this ring and can dispose of it.

Note: Keep the screws that come with the joystick, do not throw them out.

Step 2: Prepare Audio Cable
If you are using the pre-prepared TRRS cable from DigiKey, pictured in the component list, you can skip this step.
If using a different cable, you’ll need to prepare the wires for soldering. Cut the TRRS cable to length (typically 1 m). Strip off approximately 3 cm of the outer insulation. Then separate the individual inner wires and strip off approximately 0.5 cm of insulation.
Step 3: Identify Audio Cable Wires
If using the pre-prepared DigiKey cable, you can skip this step.

If using a different cable, you need to identify which wires correspond to which parts of the plug. Use a multimeter or other continuity tester to confirm. Follow this guide for checking continuity (https://www.youtube.com/watch?v=T4p8UQZqh5U) to determine which wire corresponds to the Sleeve, Ring 1, Ring 2, and Tip of the TRRS cable plug. You can use the table below to write the corresponding colours for your cable.

TRRS Plug | Digikey cable | Your cable
Tip (T) | Red
Ring 1 (R1) | White
Ring 2 (R2) | Green
Sleeve (S) | Black

## MAKER GUIDE

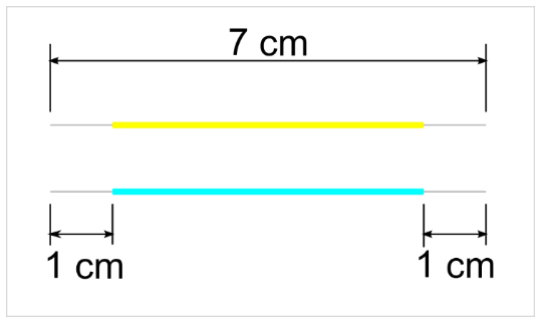
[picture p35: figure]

Files available at https://github.com/makersmakingchange/Oak-Compact-Joystick | Page 11 of 22
Step 4: Prepare Wires
Cut two pieces of wire, 7 cm long. Strip 1 cm off the ends of both wires. Twist each respective end of the wires to collect all the frayed wire strands into one. Choose one to be Wire A, and one to be Wire B.

Note: For this assembly guide, the yellow wire is Wire A and the blue wire is Wire B.

## MAKER GUIDE

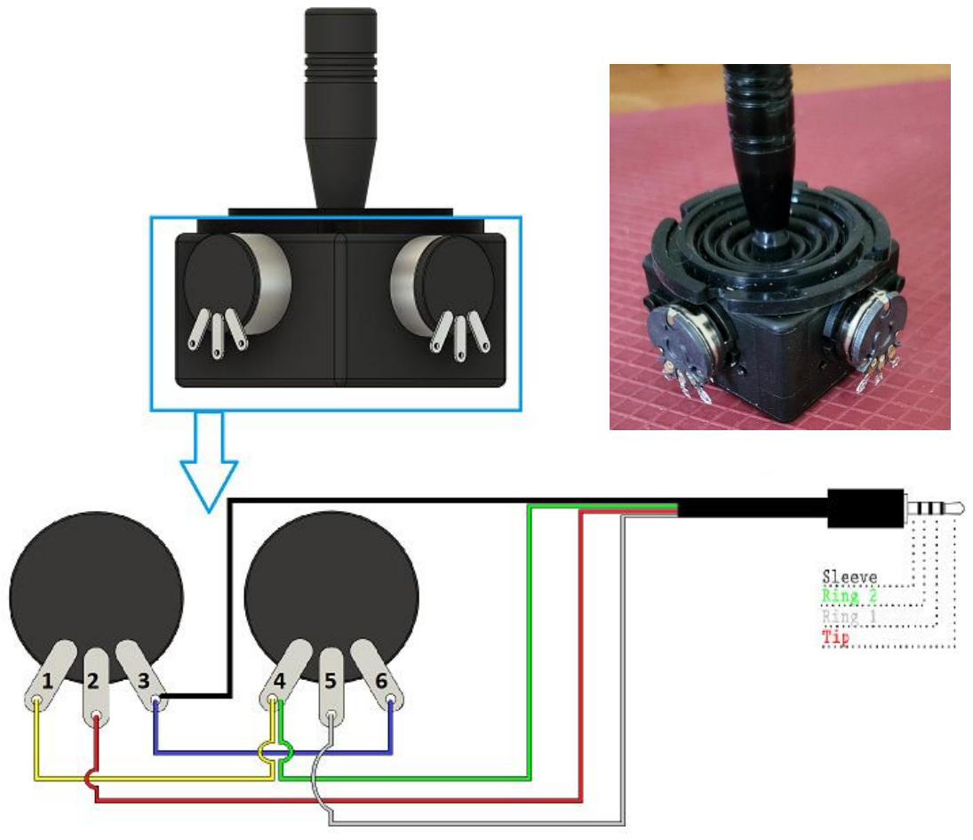
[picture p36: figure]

Files available at https://github.com/makersmakingchange/Oak-Compact-Joystick | Page 12 of 22
Step 5: Wire the Joystick
Wiring the joystick will follow the diagram below and will be broken down into multiple steps. With the joystick positioned with the two potentiometers facing you as shown, the pins are numbered 1 through 6 from left to right.

Figure 1. Joystick Wiring Guide. Image Remixed from Sparkfun, released under a CC BY 2.0 license.

Table 1: Oak Wiring

Potentiometer Pins | CONNECTION | Digikey TRRS Cable | Your TRRS Cable | Extra Wire
1 | PIN 4 | --- | ----- | Wire A
2 | Tip (T) | Red | | ----
3 | Sleeve (S) | Black | | Wire B
4 | Ring 2 (R2) | Green | | Wire A
5 | Ring 1 (R1) | White | | ----
6 | PIN 3 | ---- | ---- | Wire B

## MAKER GUIDE

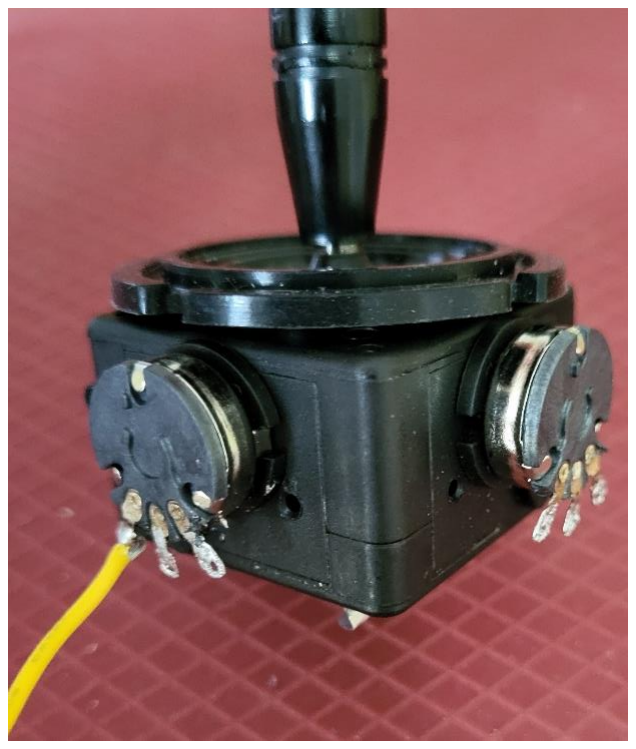
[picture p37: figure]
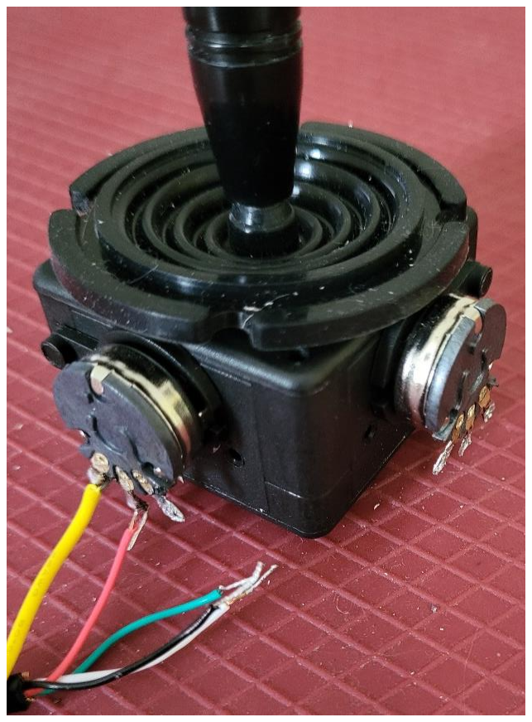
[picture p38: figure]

Files available at https://github.com/makersmakingchange/Oak-Compact-Joystick | Page 13 of 22
Step 5A: Wire and Solder Pin 1

Take Wire A and insert one end into Pin 1. Solder this into place.

Step 5B: Wire and Solder Pin 2

Take the red (tip) wire from the audio cable and insert it into pin 2. Solder this into place.

## MAKER GUIDE

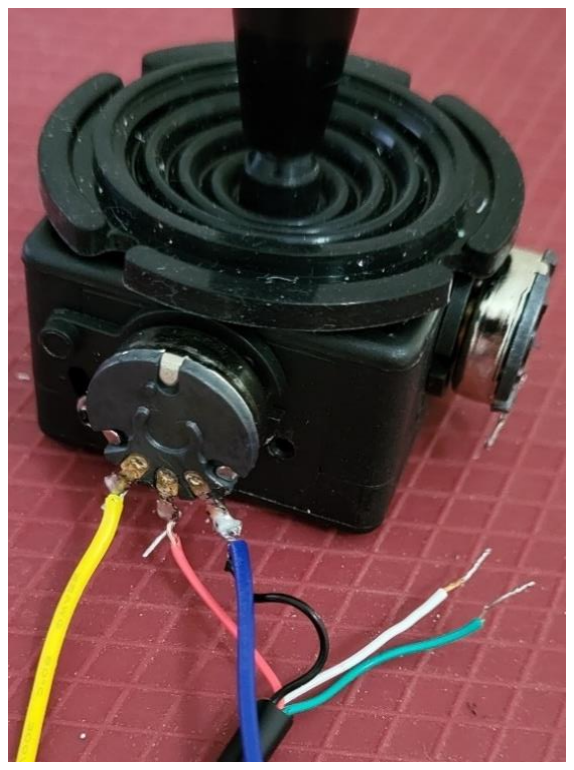
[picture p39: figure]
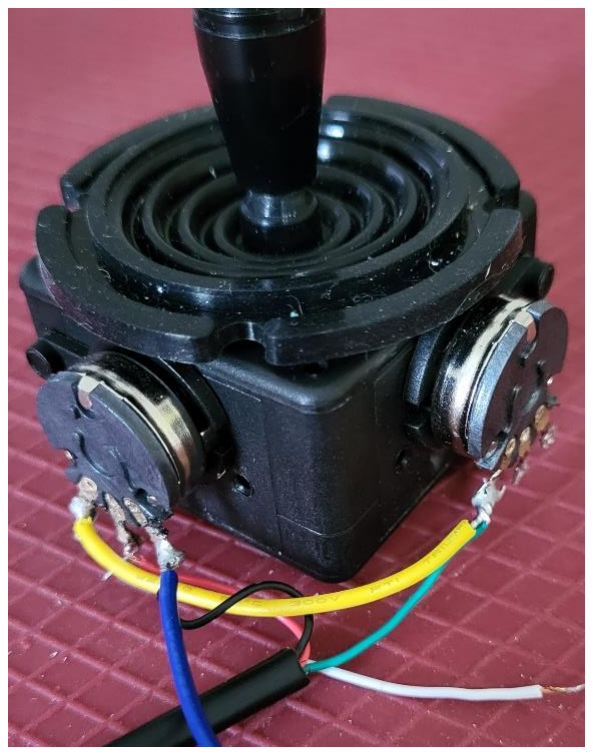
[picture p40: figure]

Files available at https://github.com/makersmakingchange/Oak-Compact-Joystick | Page 14 of 22
Step 5C: Wire and Solder Pin 3

Take the black (sleeve) wire from the audio cable and twist it together with one end of Wire B. Insert the twisted together portion of the wires into pin 3. Solder this into place.

Step 5D: Wire and Solder Pin 4

Take the free end of Wire A and twist it together with the green (Ring 2) wire from the audio cable. Insert these into pin 4 and solder into place.

## MAKER GUIDE

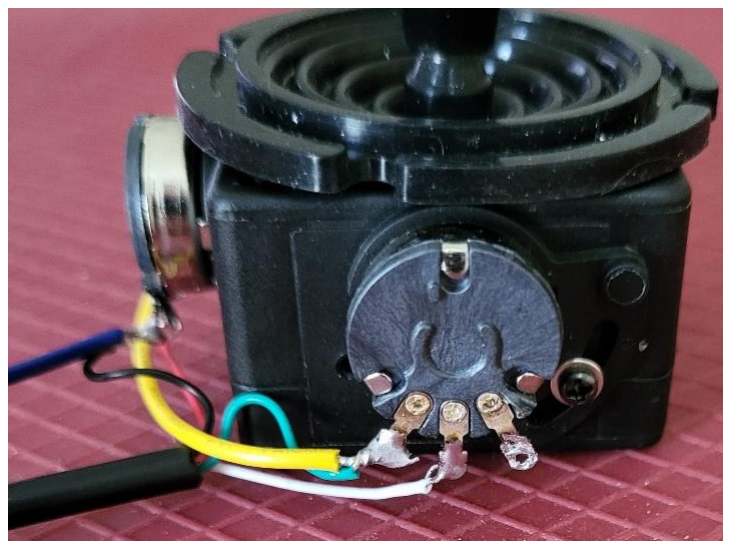
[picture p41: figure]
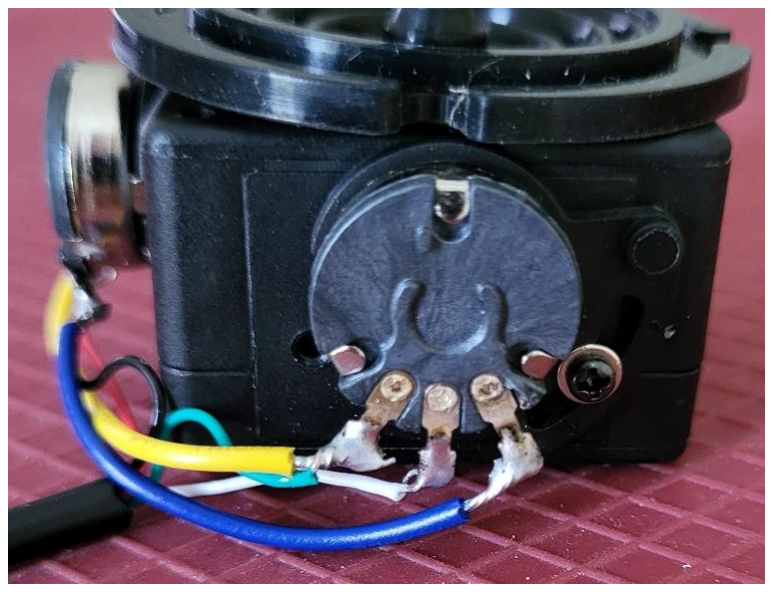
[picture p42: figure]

Files available at https://github.com/makersmakingchange/Oak-Compact-Joystick | Page 15 of 22
Step 5E: Wire and Solder Pin 5

Take the white (Ring 1) wire from the audio cable and insert it into pin 5. Solder this into place.

Step 5F: Wire and Solder Pin 6

Take the free end of Wire B and insert it into pin 6. Solder this into place.

Step 6: Test the Wiring
Visually inspect the wiring to ensure that the solder connects only the correct wires to the correct pins. If the solder is connecting anything it should not, use the soldering iron and some extra wire, solder wick, or a desoldering tool to remove solder from that area.
You can also use a multimeter to test continuity.

## MAKER GUIDE

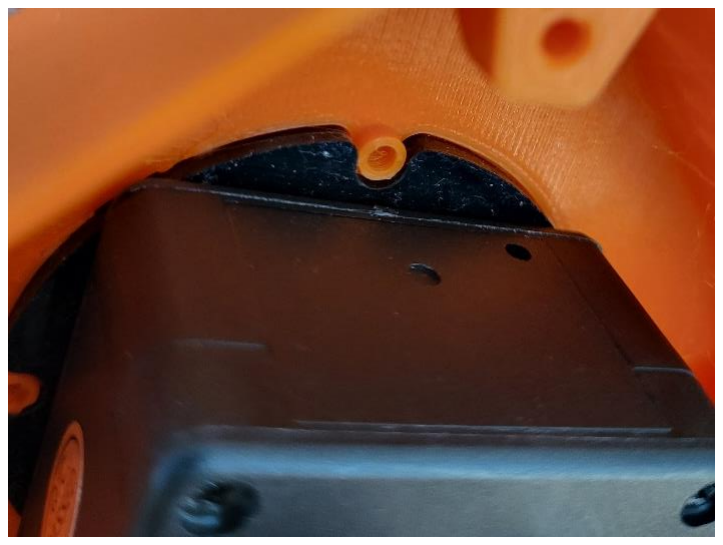
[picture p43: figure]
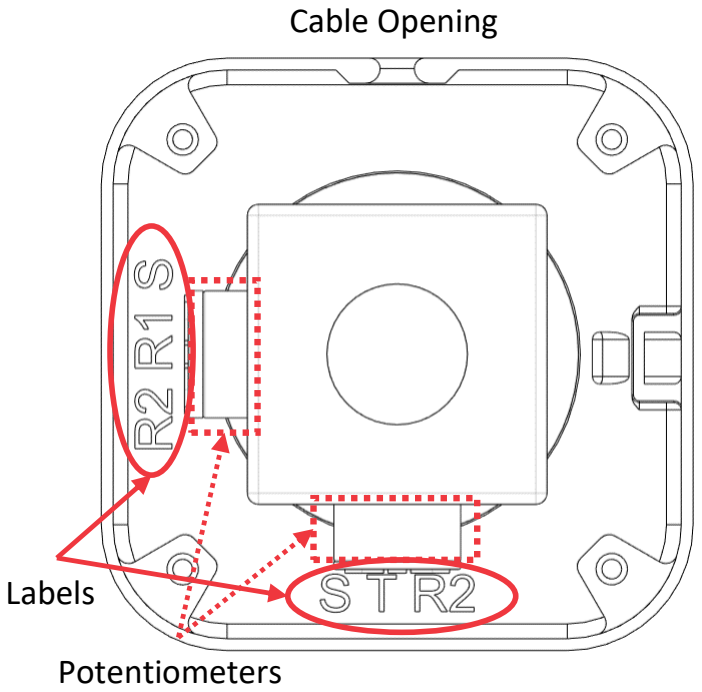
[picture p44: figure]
Cable Opening; Labels; Potentiometers

Files available at https://github.com/makersmakingchange/Oak-Compact-Joystick | Page 16 of 22
Step 7: Insert and Align the Joystick into the Enclosure Top

Insert the joystick into the enclosure. Make sure the rubber grommet fits into the grooves. There are 4 posts on the inner surface of the enclosure that the grommet should naturally align with. These posts will line up with the screw holes in the corners of the joystick.

Step 8: Rotate and Align the Joystick In the enclosure Top

While keeping the rubber grommet in place, rotate the base of the joystick so that the rectangular engravings on the inside surface match with the potentiometers on the joystick.

## MAKER GUIDE

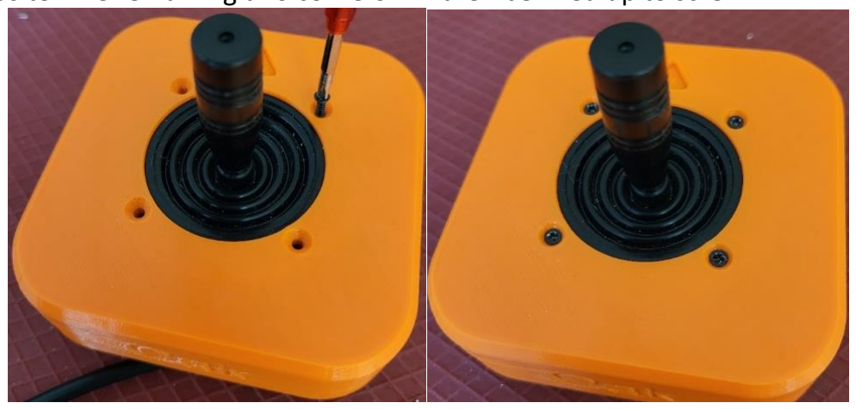
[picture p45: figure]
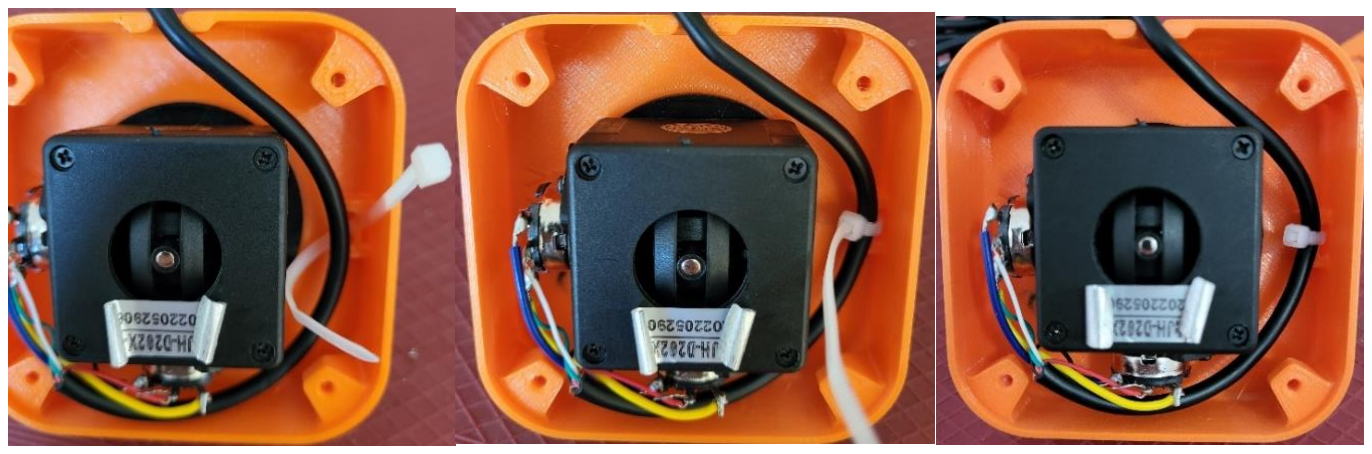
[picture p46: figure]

Files available at https://github.com/makersmakingchange/Oak-Compact-Joystick | Page 17 of 22
Step 9: Screw the Joystick into the Enclosure Top
Insert the screws that came with the joystick unit in through the top of the enclosure and screw into the joystick. It is easiest to line up one corner to start, screw it in, and then proceed with the corner diagonally opposite. The remaining two corners will then be lined up to screw in.
Step 10: Secure the Audio Cable
Route the audio cable counterclockwise around the joystick and out the opening in the front of the joystick. Insert the cable tie down through the cable tie anchor and sinch it tight around the audio cable. Trim the end of the cable tie.

## MAKER GUIDE

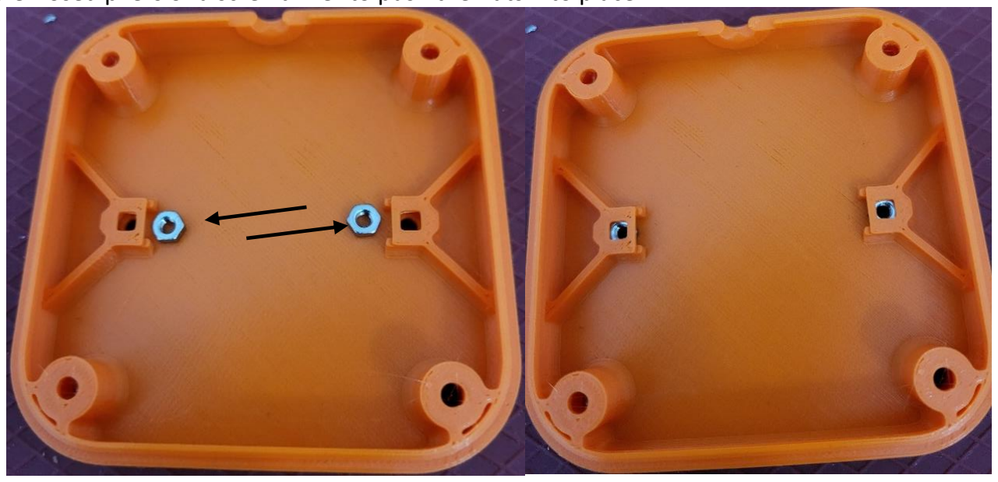
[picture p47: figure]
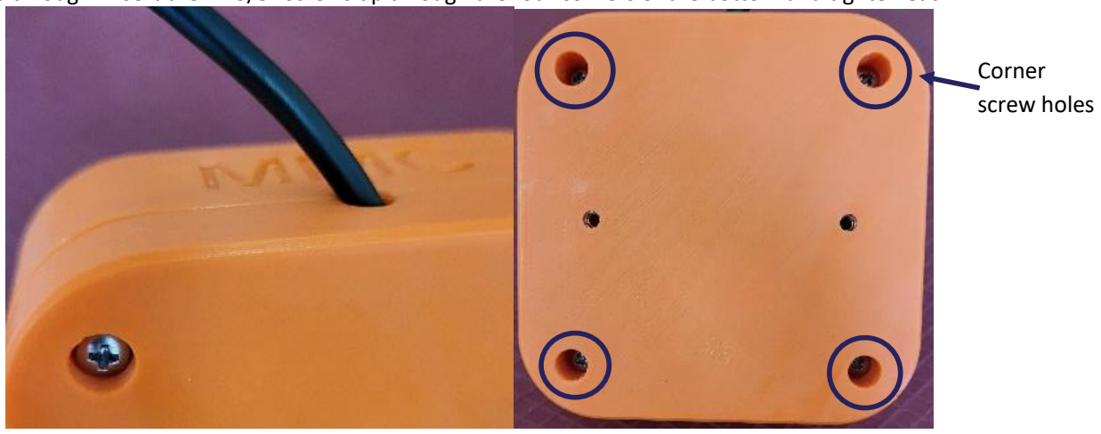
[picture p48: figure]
Corner screw holes

Files available at https://github.com/makersmakingchange/Oak-Compact-Joystick | Page 18 of 22
Step 11: Insert M3 Hex Nuts
Take the enclosure bottom and insert the M3 nuts into the as shown. You may require a tool such as needle-nosed pliers or a screwdriver to push the nuts into place.
Step 12: Assemble and Secure Enclosure
Line up the enclosure top and bottom so that the hole on the front walls line up for the audio cable to pass through. Insert the #4 3/8” screws up through the four corners of the bottom and tighten each.

## MAKER GUIDE

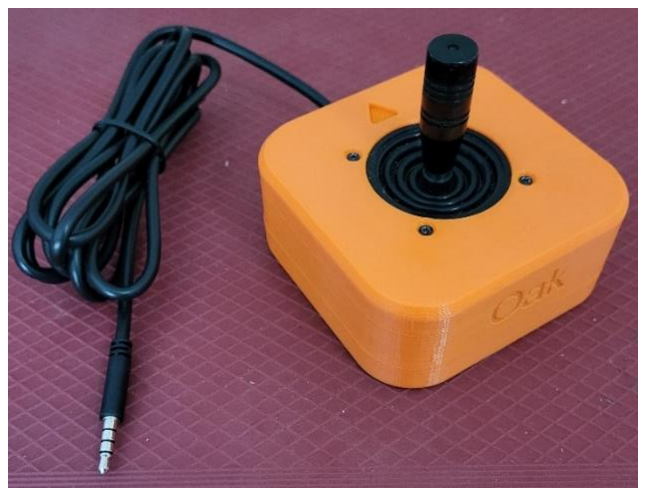
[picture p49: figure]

Files available at https://github.com/makersmakingchange/Oak-Compact-Joystick | Page 19 of 22
Step 13: Joystick Assembly Complete The joystick assembly is now complete.

## MAKER GUIDE

Files available at https://github.com/makersmakingchange/Oak-Compact-Joystick | Page 20 of 22

### Testing

Now that you have your completed Oak Joystick, you must test to make sure it is wired and assembled correctly. This can be done with a multimeter, or by plugging the joystick into one of the following: Forest Hub, Xbox Adaptive Controller (XAC), Enabled Controller Mini, Enabled Controller, or other USB-HID controller that accepts the input of an analog joystick and connecting to a computer.

### Testing using a Multimeter

A multimeter can be used to test if the wires are connected and soldered correctly. It is most important to ensure that there is no short circuit between the Sleeve (Ground) and Tip (Voltage), as this can damage the host device. It can be tricky to place the probes and move the joystick, so tape, or a second person can be helpful here.

Note: The intended joystick for this build has two 10 KΩ potentiometers, but some joysticks use 5 KΩ potentiometers, which will result in the expected multimeter readings to be halved

Test 1: Testing for Short Circuits
1. Set the multimeter to measure resistance in the 1-
10 KΩ range.
2. Hold the tip of the red probe of the multimeter to the Sleeve (Voltage) of the TRRS cable.
3. Hold the tip of the black probe of the multimeter to Ring 2 (Ground) on the TRRS cable.
4. Confirm that the resistance is between 4 – 5 KΩ.
a. Between 4 – 5 KΩ: No shorts. Proceed to next test.
b. Less than 50 Ω: There is a short circuit between a Ground and Voltage pin (Pins 1, 3, 4, and 6). This must be fixed to prevent damaging a host device. Open the joystick and review/fix your soldering joints.
c. Other values: There is a wiring problem. Open the joystick and review/fix your soldering joints.

If you have no short circuits, you can move on to testing the joystick directions. This can be done with either the multimeter, or with a USB-HID gamepad that accepts an analog joystick.

## MAKER GUIDE

Files available at https://github.com/makersmakingchange/Oak-Compact-Joystick | Page 21 of 22

Test 2: Testing Vertical Joystick Axis
1. Hold the tip of the red probe of the multimeter to the Sleeve (Voltage) of the TRRS cable.
2. Hold the tip of the black probe to Ring 1 (Y-axis) on the TRRS cable.
3. While holding the multimeter probes in place, move the joystick fully in the UP ↑ direction.
a. You may require a second person to hold the probes in place or move the joystick.
b. Otherwise, the joystick can be held in place with some tape to leave your hands free to hold the multimeter probes in place.
4. Read the resistance on the multimeter:
a. Less than .05 KΩ: The Y-axis potentiometer is wired correctly.
b. Otherwise, review the wiring diagram and ensure your wiring matches.
5. Release the joystick back to neutral position.

Test 3: Testing Horizontal Joystick Axis
1. Hold the tip of the red probe of the multimeter to the Sleeve (Voltage) of the TRRS cable.
2. Hold the tip of the black probe to Tip (X-axis) of the TRRS cable.
3. While holding the multimeter probes in place, move the joystick fully in the RIGHT → direction.
a. You may require a second person to hold the probes in place or move the joystick.
b. Otherwise, the joystick can be held in place with some tape to leave your hands free to hold the multimeter probes in place.
4. Read the resistance on the multimeter.
a. Less than .05 KΩ: The X-axis potentiometer is wired correctly.
a. Otherwise, review the wiring diagram and ensure your wiring matches.
5. Release the joystick back to neutral position.

## MAKER GUIDE

Files available at https://github.com/makersmakingchange/Oak-Compact-Joystick | Page 22 of 22

Troubleshooting
If tests 2 or 3 fail, here are the likely scenarios to address.

Test 2 Fail
If the multimeter reading does not decrease when moving the joystick from the neutral position the UP direction, then the Voltage and Ground pins (Pins 4 and 6) are opposite and need to be swapped.

If the multimeter reading does not change, then the X and Y axis pins (2 and 5) are opposite and need to be swapped.

Test 3 fail
If the multimeter reading does not decrease when moving the joystick from the neutral position the RIGHT direction, then the Voltage and Ground pins (Pins 1 and 3) are opposite and need to be swapped.

If the multimeter reading does not change, then the X and Y axis pins (2 and 5) are opposite and need to be swapped.

### Testing using an USB-HID Gamepad Device

Before plugging the joystick into a USB-HID Gamepad Device, ensure that there is no short circuit between the Tip and the Sleeve.

1. Plug the joystick into the analog joystick input for the host device.
a) X1 or X2 on an Xbox Adaptive Controller.
2. Plug the host device into a computer.
3. If using Windows, open “Set up USB Game Controllers” from the Control Panel. You can find this by searching your computer in the search bar next to the Windows icon.
a) If using a Mac, use https://hardwaretester.com/gamepad
4. Select the host device from the list of controllers and go to “Properties”.
5. Move your joystick and observe the movement of the cross hatch in the “Axes” window. Ensure it moves in the proper directions when you move the joystick (the arrow points in the up direction). If not, open the joystick and check your connections.

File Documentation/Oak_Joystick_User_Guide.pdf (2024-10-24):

V1.0.2 | October 2024

## Oak Compact Joystick

## USER GUIDE

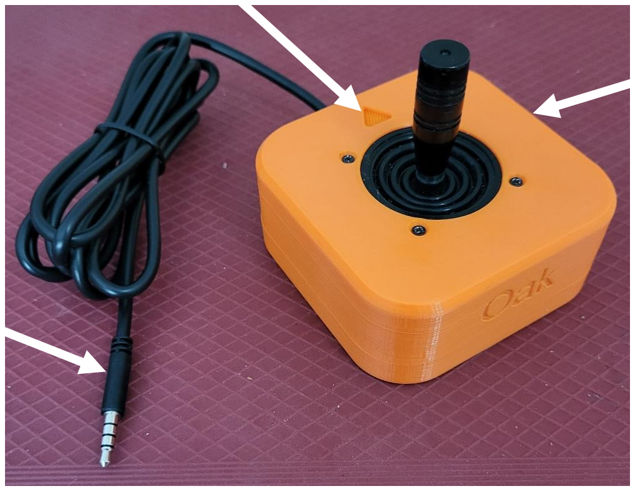
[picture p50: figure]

© 2023-2024 by Neil Squire Society. (https://www.neilsquire.ca/) This work is licensed under the CC BY SA 4.0 License: http://creativecommons.org/licenses/by-sa/4.0 Files available at https://github.com/makersmakingchange/Oak-Compact-Joystick

### Introduction

The Oak Compact Joystick is a midsized joystick compatible with the XAC or other analog input joystick devices. It has a range of toppers that can be 3D printed as well.

### Features

### Usage

Using the Joystick
1. Plug the 3.5 mm TRRS cable from the joystick into the host device analog joystick input (such as the Xbox Adaptive Controller). If using the Xbox Adaptive Controller, plug it into X1 to use at the left joystick, or plug into X2 to use as the right joystick.
2. Ensure the arrow on the joystick is pointing in the “up/forward” direction, away from the user.
3. Mount the device if needed (see below).
4. Move joystick as you would with a standard controller (forward, left, backward, right).

Compatibility
This device is compatible with the Xbox Adaptive Controller (XAC), (https://www.xbox.com/en-CA/accessories/controllers/xbox-adaptive-controller) Forest Hub, (https://github.com/makersmakingchange/Forest-Joystick-Mouse-Hub) Enabled Controller, (https://makersmakingchange.com/project/enabled-controller/) Enabled Controller Mini, (https://www.makersmakingchange.com/s/product/enabled-controller-mini/01tJR0000006991YAA) and any other device that accepts a TRRS analog joystick input.

Oak Joystick

TRRS Cable
Output

Up/Forward Arrow

## USER GUIDE

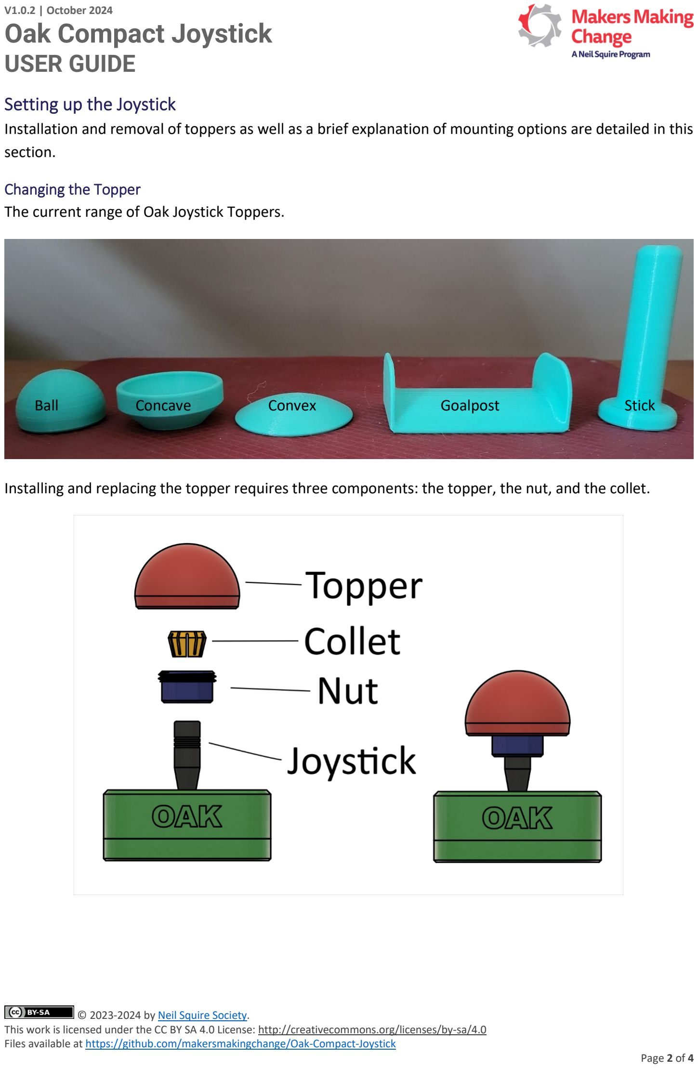
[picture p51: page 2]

© 2023-2024 by Neil Squire Society. (https://www.neilsquire.ca/)

### Setting up the Joystick

Installation and removal of toppers as well as a brief explanation of mounting options are detailed in this section.

Changing the Topper
The current range of Oak Joystick Toppers.

Installing and replacing the topper requires three components: the topper, the nut, and the collet.

Ball | Concave | Convex | Goalpost | Stick

## USER GUIDE

© 2023-2024 by Neil Squire Society. (https://www.neilsquire.ca/)

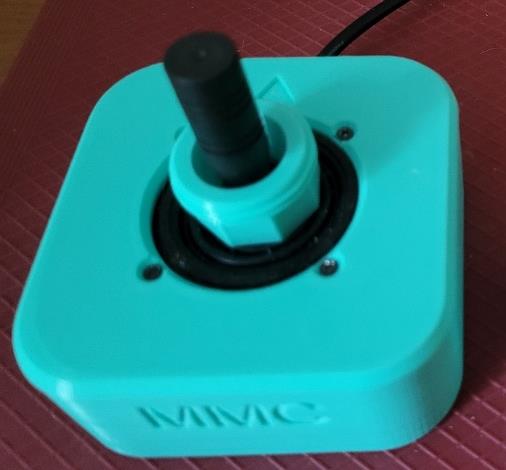
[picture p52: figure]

Step 1: Add Nut

Place the nut over the black joystick shaft. The threads should be towards the top of the joystick, while the octagonal section should be towards the bottom.

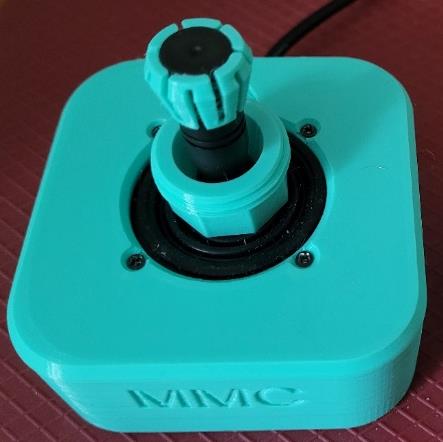
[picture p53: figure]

Step 2: Install Collet

Place the collet on the black joystick shaft. The two ends of the collet have different thicknesses to them. The side of the collet that is thinner should go over the joystick shaft first, so that the thicker side is pointing up and away from the joystick. Note: if the collet does not sit at least ¾ of the way into the nut in this orientation, then the collet is likely upside down.

Step 3: Fasten Topper

Slide the nut up the joystick shaft just under the collet and line up the threads on the bottom of the topper with the nut. Thread the nut into the topper and tighten by hand.

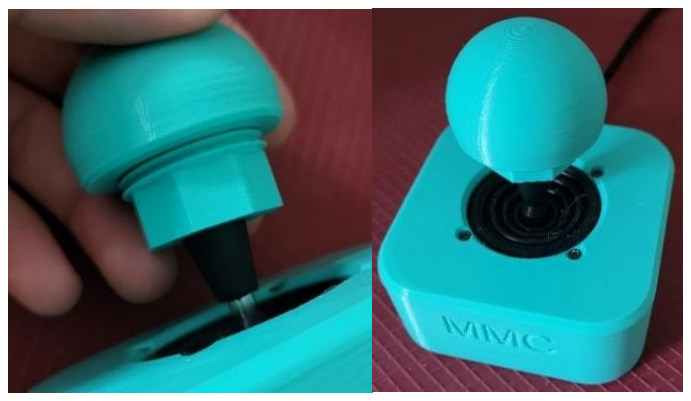
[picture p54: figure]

To remove the topper, simply unscrew the nut and remove the topper. Note that you may require pliers or a wrench to grip the octagonal bottom of the nut if the topper is screwed on too tight.

Mounting the Joystick
The Oak Compact Joystick can be mounted using various methods, depending on your preference and how you can best access it. See the OpenAT Joystick Setup Guide (https://github.com/makersmakingchange/OpenAT-Joysticks/Resources/OpenAT_Joystick_Setup_Guide.pdf) for more information on different ways to mount the joystick. A few options are:

## USER GUIDE

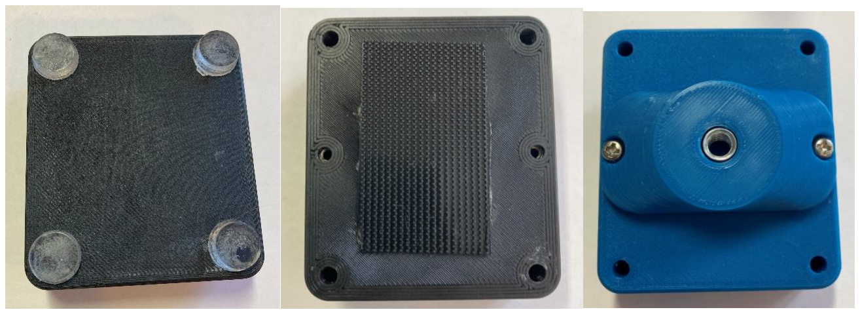
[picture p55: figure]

© 2023-2024 by Neil Squire Society. (https://www.neilsquire.ca/)

1. Tabletop
a. Alone
b. With non-slip pads
c. With hook and loop fasteners (such as Velcro)
2. Using a mount adapter
a. Camera mount adapter used with camera mount, or any mount with ¼-20 threads

Note: The mounting options are shown on a different joystick but will apply the same to this one.

### Specifications

Joystick Range of Motion | ± 25°
Joystick Range of Motion at Tip | ± 30 mm (default, changes with topper)
Joystick Activation Force | 525 grams
Total Height | 65 mm
Enclosure Height | 35 mm
Enclosure Width | 80 mm
Enclosure Length | 80 mm
Weight | 152 grams

### Cleaning

Wipe the outside of the device with a lukewarm, damp cloth. Do not use hot water on this device or the plastic housing may warp. Do not submerge the device.

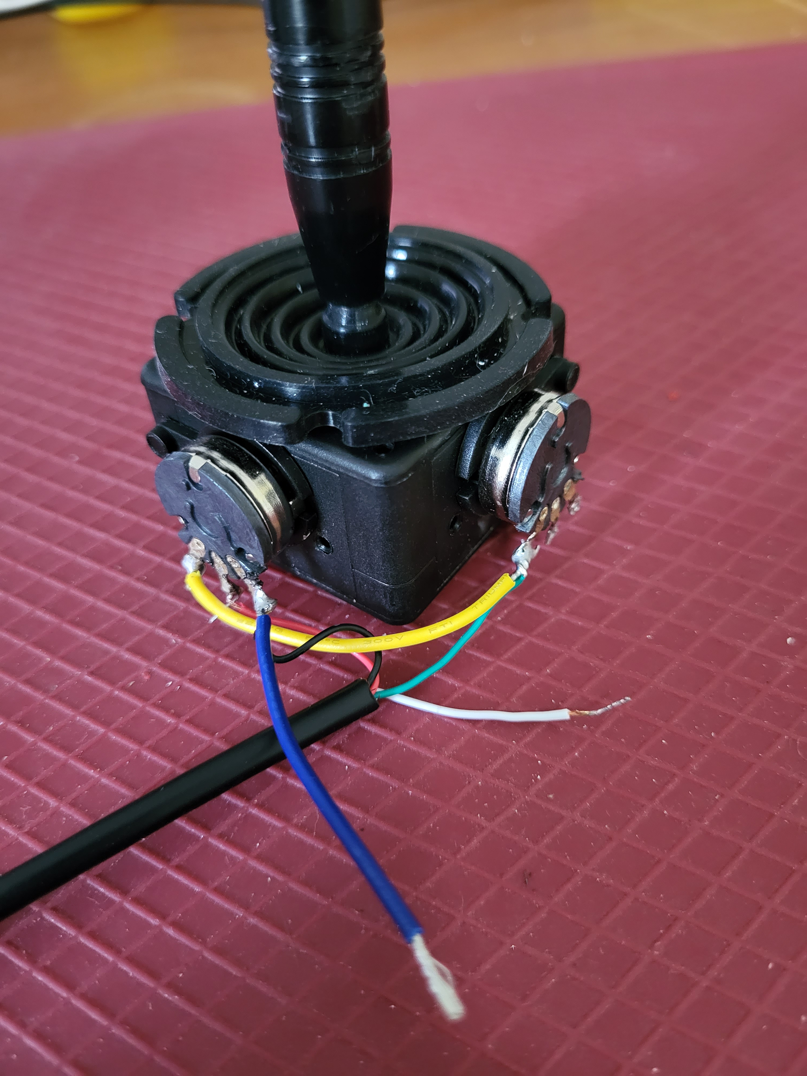
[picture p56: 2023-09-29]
Documentation/Working_Documents/Assets/Assembly_Photos/Oak_joystick_solder_5.jpg

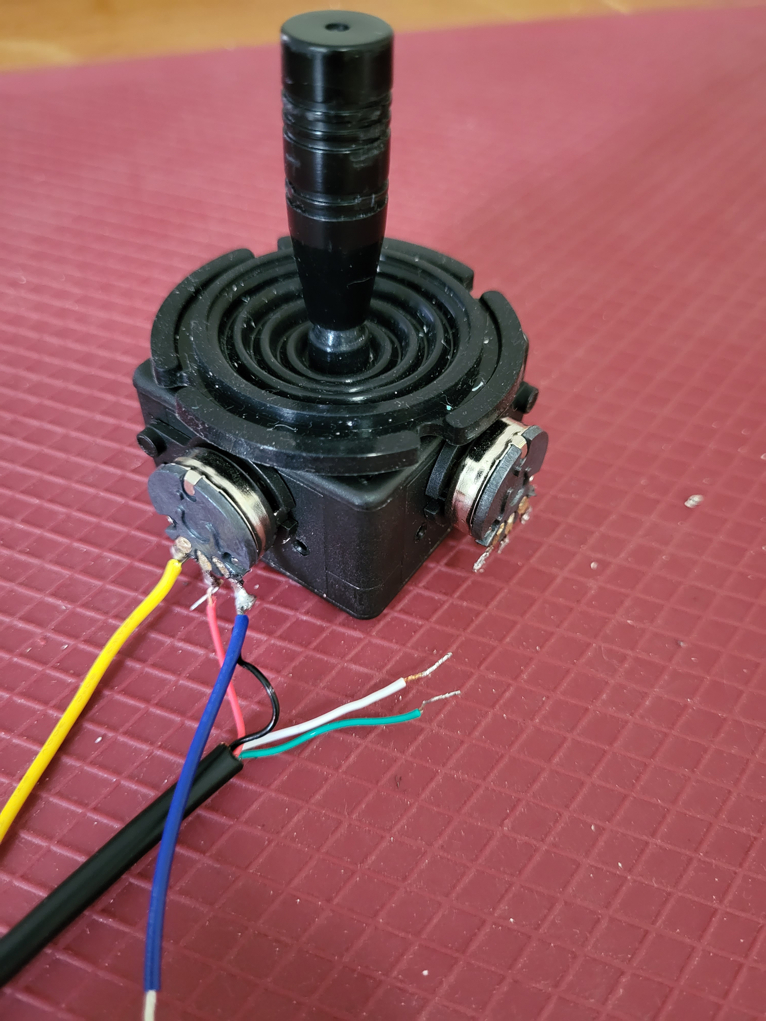
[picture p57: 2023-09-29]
Documentation/Working_Documents/Assets/Assembly_Photos/Oak_joystick_solder_4_4.jpg

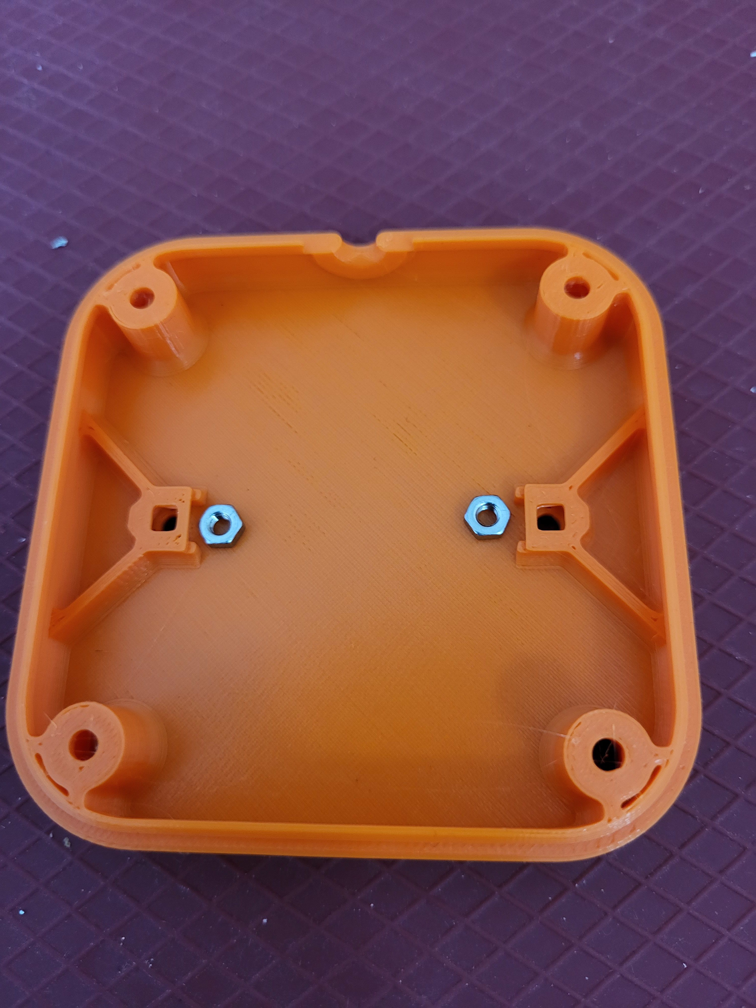
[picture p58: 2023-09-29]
Documentation/Working_Documents/Assets/Assembly_Photos/Oak_inserting_nuts.jpg

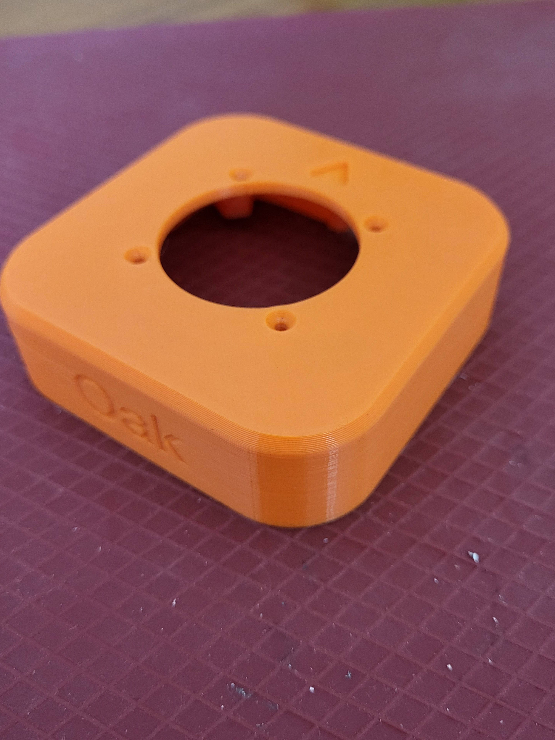
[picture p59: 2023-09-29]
Documentation/Working_Documents/Assets/3D_Print_Photos/Oak_Enclosure_Top_3.jpg

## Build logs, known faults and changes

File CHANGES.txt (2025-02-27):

------OAK COMPACT JOYSTICK------
           Changelog
===============================
Version 1.0.3 2025-Feb-27
 - Added CAD and STL files for stronger goalpost toppers

Version 1.0.2 2024-Oct-07
 - Added CAD files and updated documentation for Topper Wrench

Version 1.0.1 2024-Oct-10
 - Added CAD files for Topper_Nut, Topper_Collet, and Topper_Interface

Version 1.0 2023-Sept-27
 - Updated enclosure cable tie anchor and internal labelling
 - Updated topper sizes
 - Updated documentation 
    - Included a topper guide
    - Consolidated maker documents into a single Maker Guide
 - No longer paried specifically with the Enabled Controller Mini

Version 0.9    2023-Jun-30
- Enclosure optimised for reduced print time and improved build redundancy
- Topper connection collet design
- Updated toppers
- 5 parametric toppers
- Updated documentation to be for just the analog variant build
- Paired the analog build with Enabled Controller Mini and custom Mouse and Gamepad code

Version 0.2 	2023-May-18
 - Initial commit
 - Oak Compact Joystick with 4 optional toppers and an optional camera mount adapter
 - Both USB and analog variants available

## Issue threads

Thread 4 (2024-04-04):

Create Topper wrench / installation aid

jakemcivor, 2024-04-04:
Create a 3D printable wrench and/or jig to make it easier to securely tighten topper nut. Ideally something so a user could add a topper with one hand.

jakemcivor, 2024-10-24:
Resolved in V1.0.2

Closed 2024-10-24.

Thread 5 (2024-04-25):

Broken link in documentation

MHache1717, 2024-04-25:
In the Oak Joystick Maker Guide a link is provided (under mounting, page 4) to:

https://github.com/makersmakingchange/OpenAT-Joysticks/Resources/OpenAT_Joystick_Setup_Guide.pdf

That's supposed to discuss mounting options. Link is broken.

Marc

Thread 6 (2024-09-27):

Nut and Collet .STEP/.f3d file

DRA6N, 2024-09-27:
Please include the CAD files (f3d) for the nut and collet to use for customizing as per request of the requestee.

jakemcivor, 2024-10-01:
Thanks for noticing the missing files. I've added them to the repository. Please let us know if you run into any more issues.

Topper_Interface (Portion to create custom topper):
https://github.com/makersmakingchange/Oak-Compact-Joystick/raw/refs/heads/main/Design_Files/CAD_Files/Topper_Interface/Oak_Topper_Interface.f3d

Topper_Nut:
https://github.com/makersmakingchange/Oak-Compact-Joystick/raw/refs/heads/main/Design_Files/CAD_Files/Topper_Interface/Oak_Topper_Nut.f3d

Topper_Collet:
https://github.com/makersmakingchange/Oak-Compact-Joystick/raw/refs/heads/main/Design_Files/CAD_Files/Topper_Interface/Oak_Topper_Collet.f3d

Closed 2024-10-01.

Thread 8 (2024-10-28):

Screws no longer sold individually

bradleywell, 2024-10-28:
The Serpac 6005 sheet metal screws used are no longer sold individually and now comes in bulk lots of 1000. Need to find a replacement. Mouser version is still sold individually.

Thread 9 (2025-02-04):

Create and Add Willow-Joystick like Non-Slip Base for Oak

jakemcivor, 2025-02-04:
The Willow Joystick has a non-slip base that connects to the mounting interface and has spots for non-slip feet to prevent the device from slipping around on the surface.

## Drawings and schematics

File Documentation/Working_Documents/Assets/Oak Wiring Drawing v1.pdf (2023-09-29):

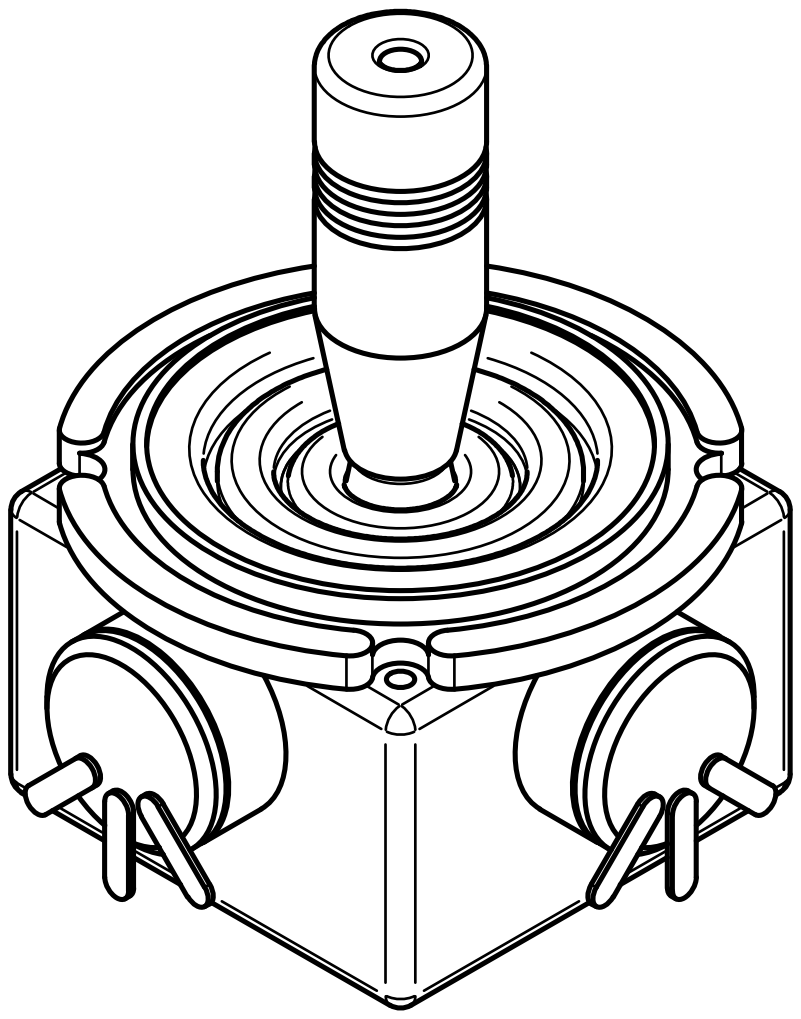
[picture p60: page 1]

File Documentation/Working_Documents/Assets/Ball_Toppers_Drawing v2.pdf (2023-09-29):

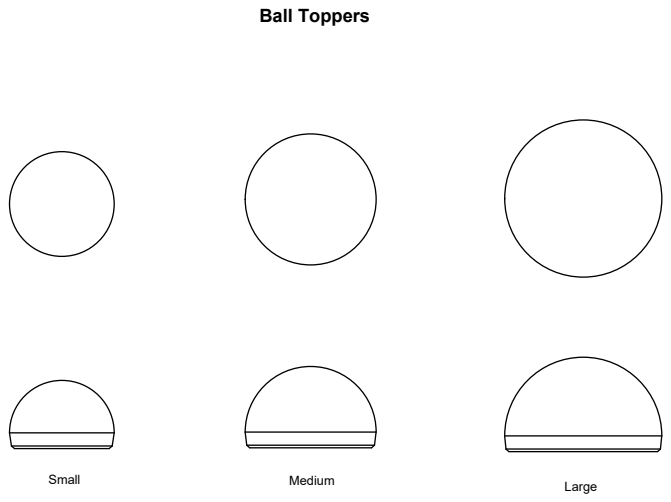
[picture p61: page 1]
Ball Toppers

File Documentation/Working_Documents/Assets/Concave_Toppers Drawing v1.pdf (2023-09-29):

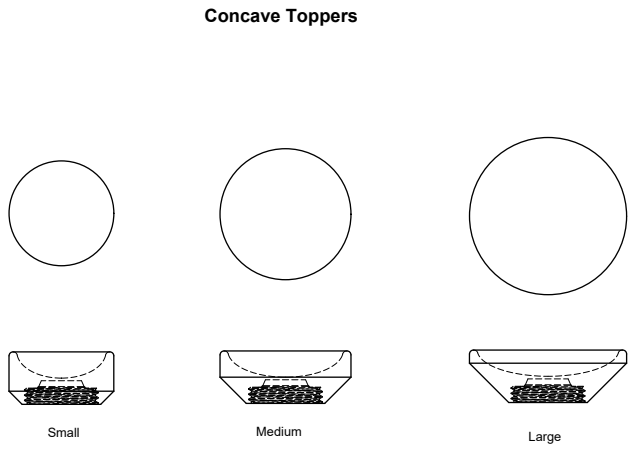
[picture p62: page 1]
Concave Toppers

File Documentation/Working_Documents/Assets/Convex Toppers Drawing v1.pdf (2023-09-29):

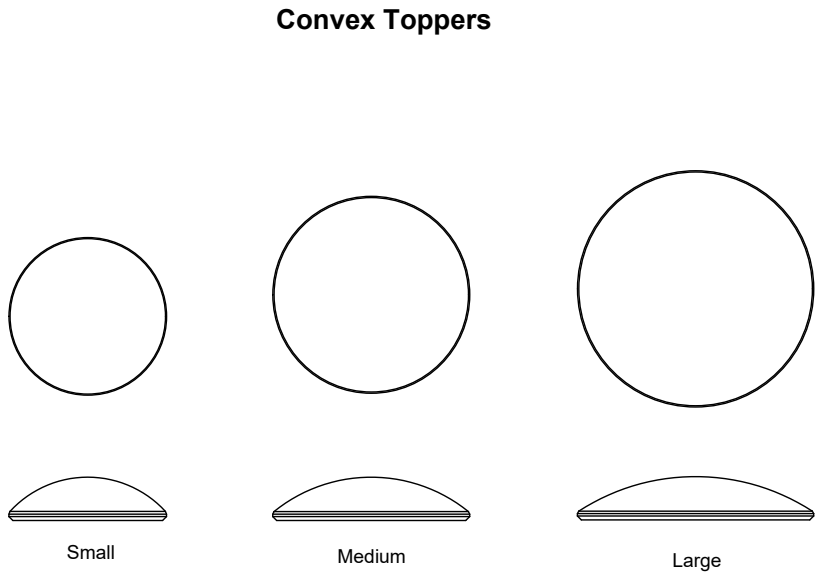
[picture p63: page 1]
Convex Toppers

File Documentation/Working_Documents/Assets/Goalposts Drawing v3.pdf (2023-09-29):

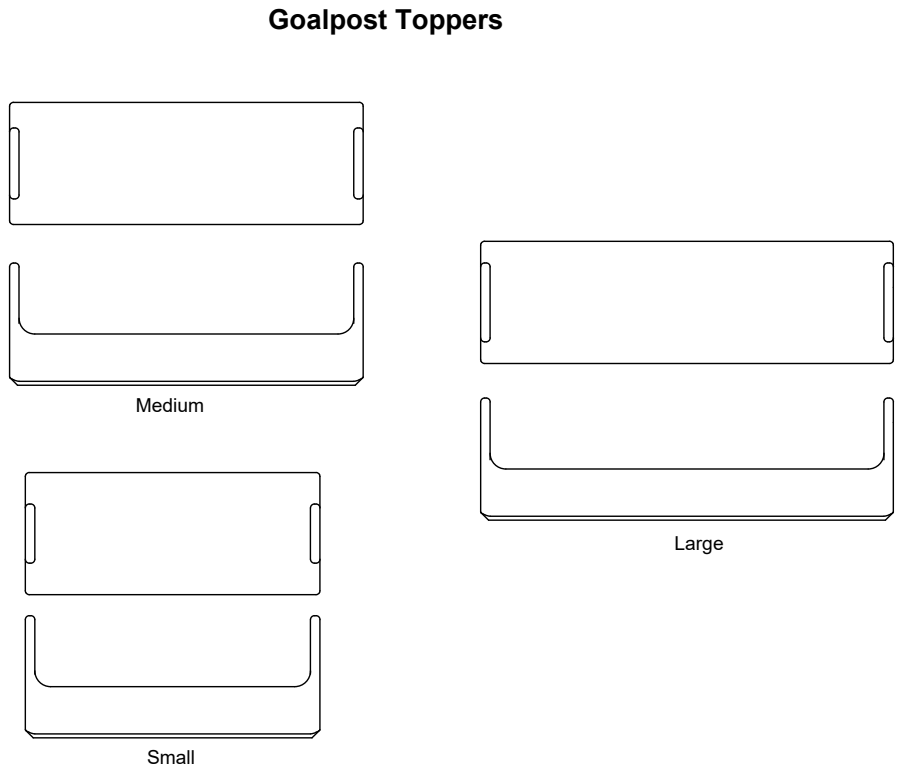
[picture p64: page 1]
Goalpost Toppers

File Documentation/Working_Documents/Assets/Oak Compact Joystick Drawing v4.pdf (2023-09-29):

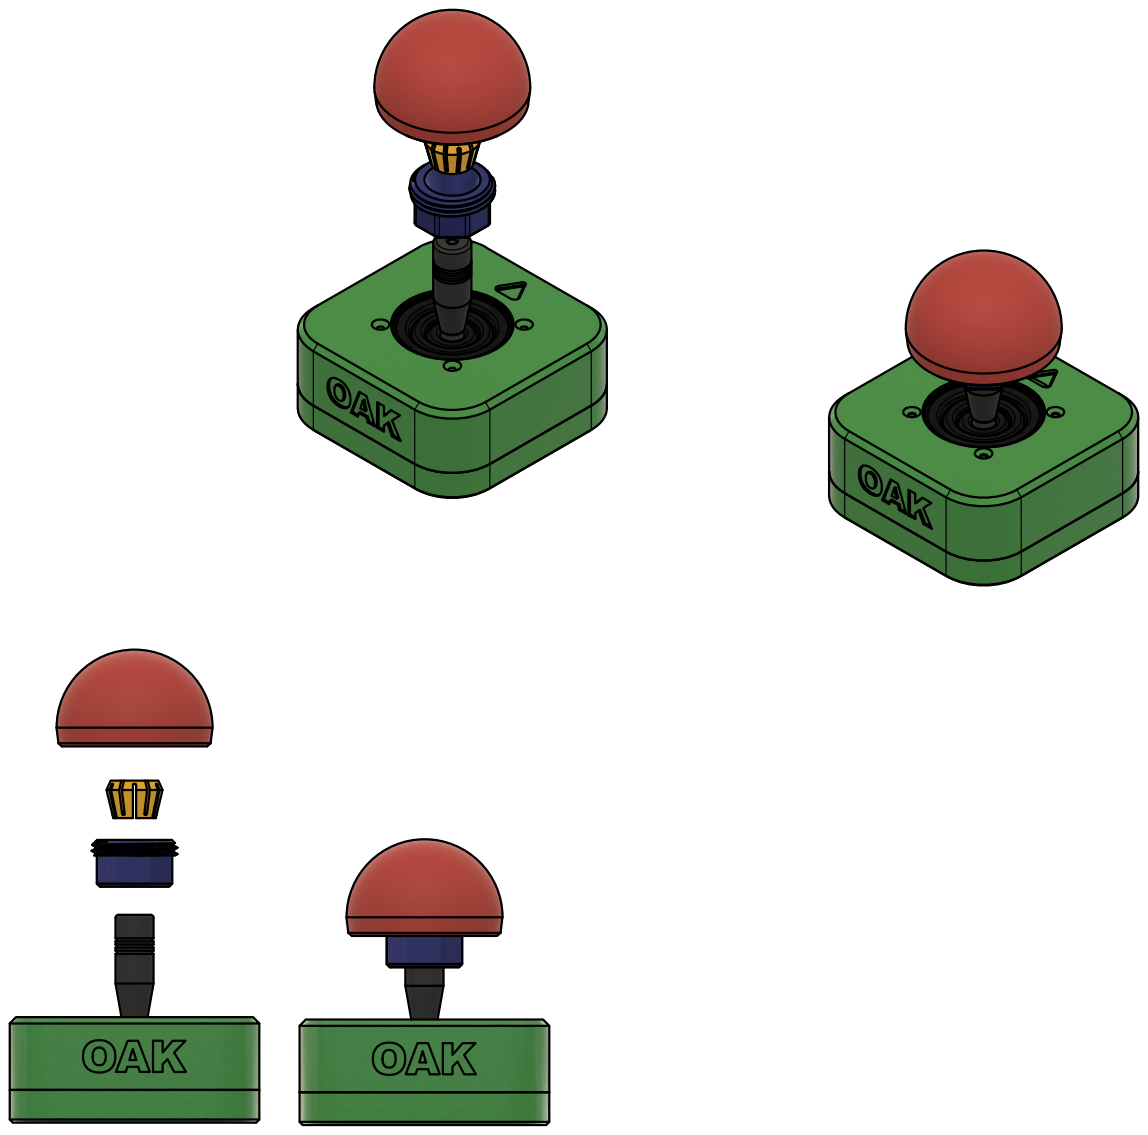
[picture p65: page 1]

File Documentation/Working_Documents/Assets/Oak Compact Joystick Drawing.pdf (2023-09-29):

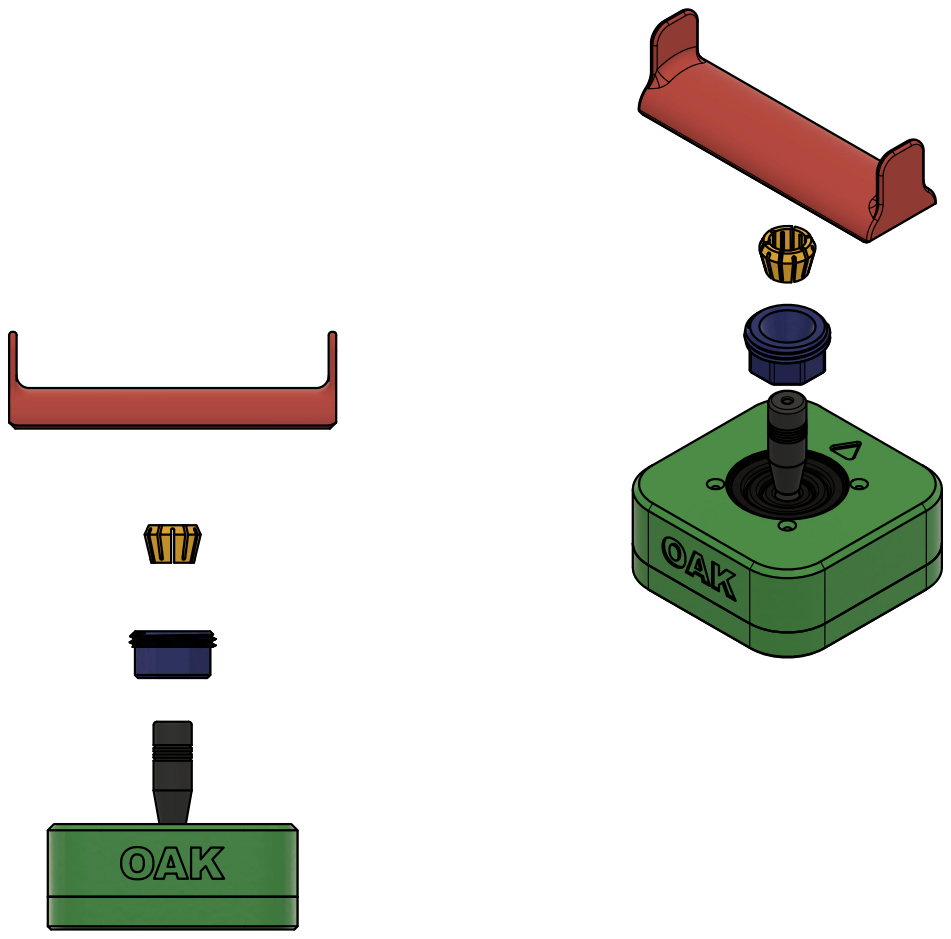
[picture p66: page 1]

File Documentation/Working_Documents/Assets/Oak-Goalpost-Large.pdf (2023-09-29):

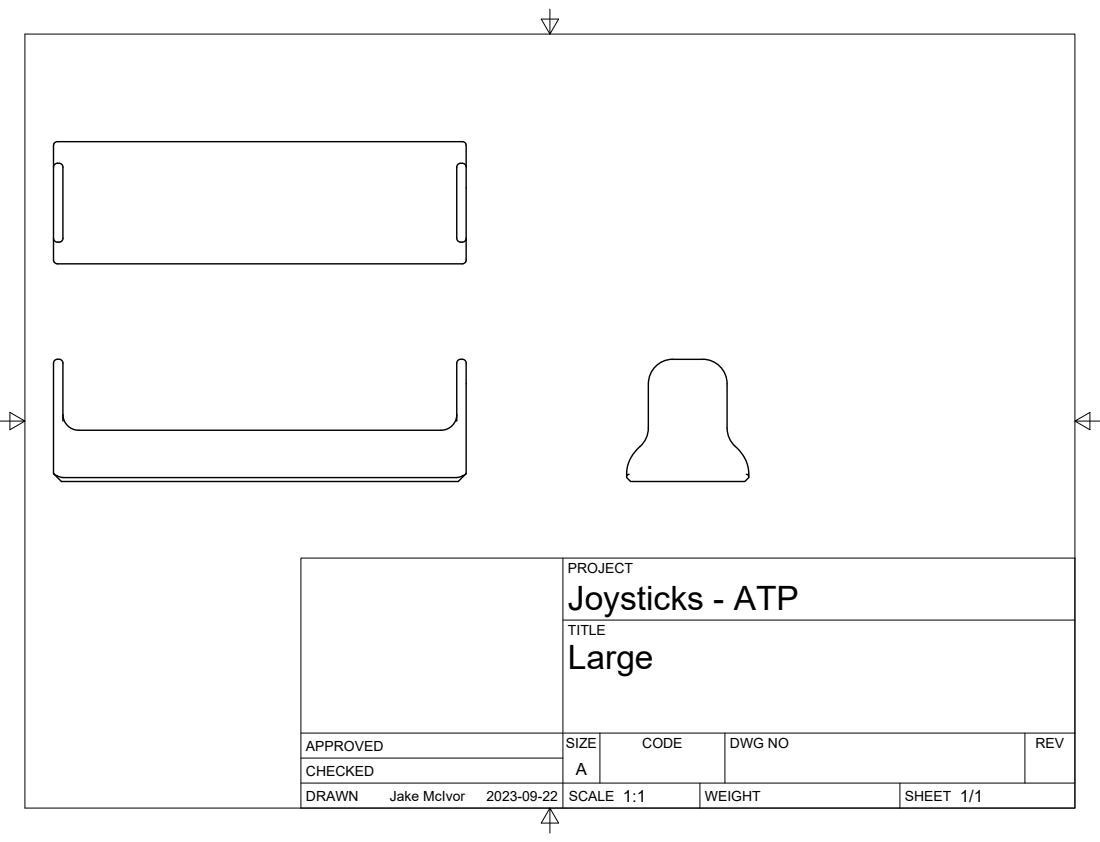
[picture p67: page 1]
SIZE; CODE; DWG NO; REV; Jake McIvor; Joysticks - ATP

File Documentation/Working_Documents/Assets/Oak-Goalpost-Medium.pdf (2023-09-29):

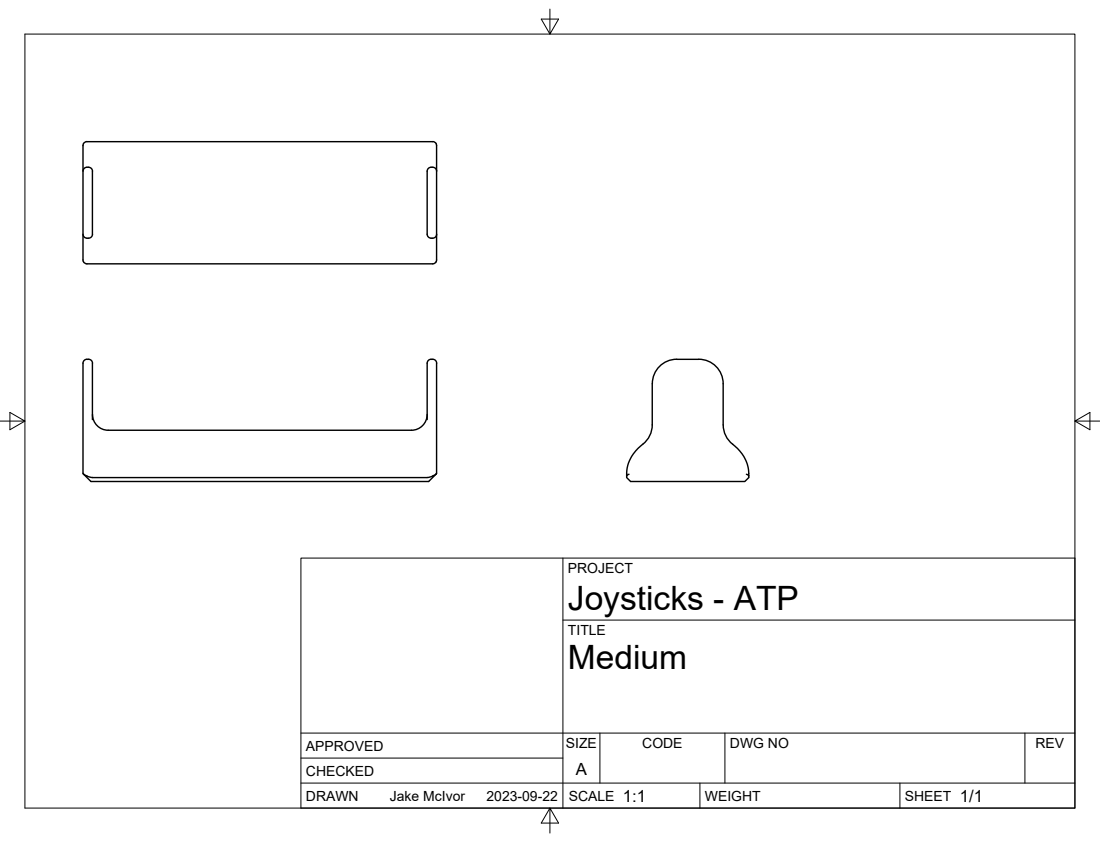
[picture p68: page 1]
SIZE; CODE; DWG NO; REV; Jake McIvor; Joysticks - ATP

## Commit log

2023-05-17 Delete Device-Name.jpg
    Remove template photo
2023-05-17 Move assembly photos
2023-09-28 Add Topper_Interface step file
    To help facitilate creation of custom toppers.
    [Topper_Interface.step]
2023-10-17 Update README.md
    3D Printing Files Typo
2024-10-01 Add CAD files for topper interface
    Collet
    Topper_Nut
    Topper_Interface
    [Collet.f3d, Collet.step, Topper_Interface.f3d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]
2024-10-01 Update and reorganize topper files
    [Oak_Topper_Collet.f3d, Oak_Topper_Collet.step, Oak_Topper_Collet.stl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]
2024-10-01 Add topper wrench
    Add 3D printable wrench for tightening toppers.
    [Oak_Topper_Wrench.f3d, Oak_Topper_Wrench.step, Oak_Topper_Wrench.stl]
2024-10-17 Added joystick mount adapters
    [Joystick RAM Mount Adapter v5.f3d, Joystick_Camera_Mount Narrow v3.f3d, Joystick_Camera_Mount_Adapter.stl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]
2024-10-24 Re-organize photos
    Move assembly and 3d printing photos from main photo folder to documentation
2024-10-24 Update to 1.0.2
    Add topper wrench.
    [Oak_Joystick_BOM.csv, Oak_Joystick_BOM.xlsx]
2025-02-27 Strengthened Goalpost Toppers
    Changed print orientation of the goalpost toppers to make them stronger
    [Goalpost_Topper.f3d, Goalpost_Topper.f3z, Large_Goalpost Topper.stl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]
2026-04-01 Update README.md
    added mounting options
